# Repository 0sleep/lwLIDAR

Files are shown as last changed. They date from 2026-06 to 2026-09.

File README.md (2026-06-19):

# lwLIDAR

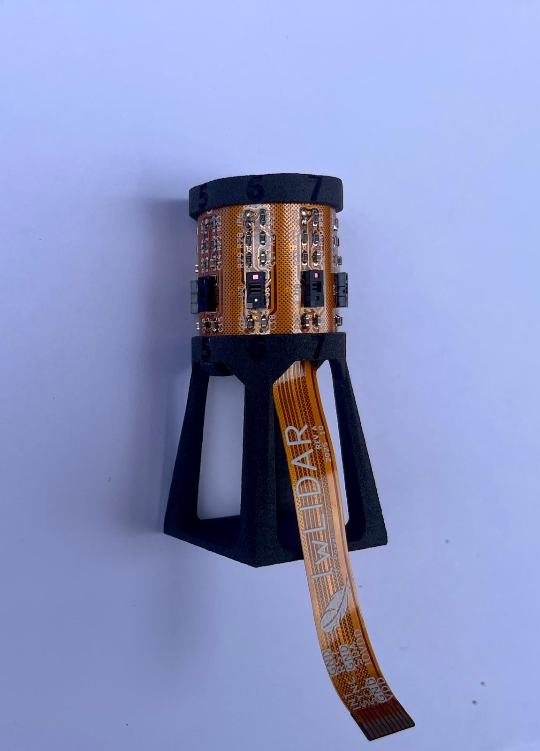
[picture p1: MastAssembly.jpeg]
Image of sensor assembly

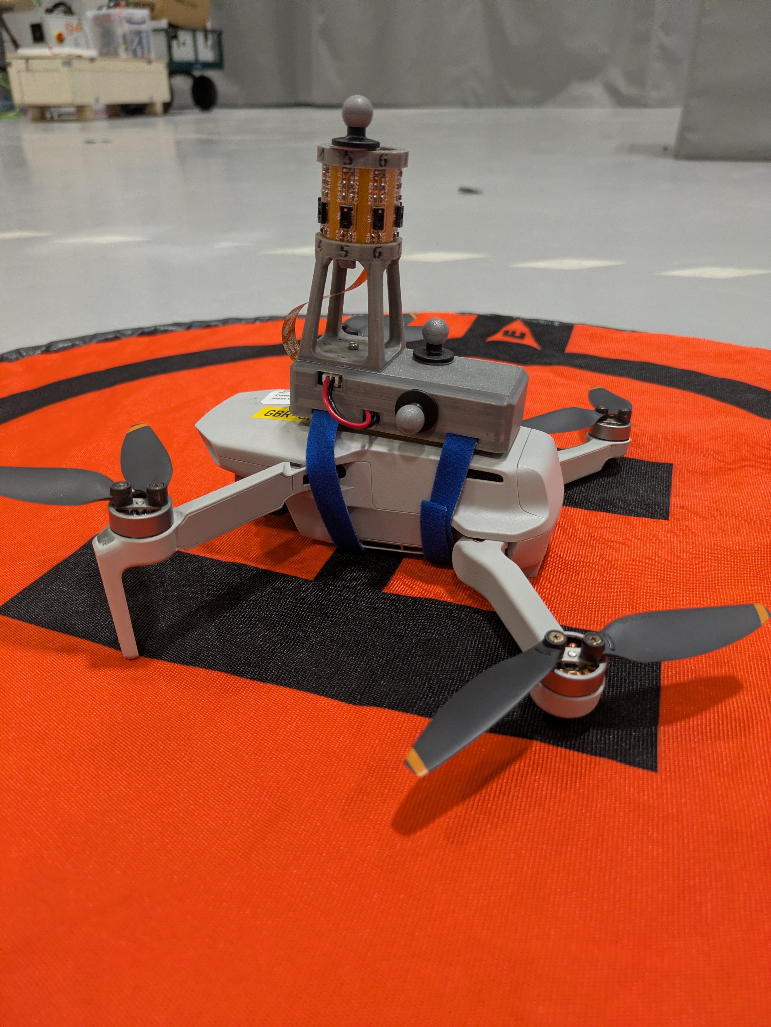
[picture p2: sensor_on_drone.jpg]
Image of sensor mounted to a drone


# Summary
lwLIDAR is a research project aiming to design, implement and test a low-cost compact 3D LiDAR for use in constrained robotics research. It consists of an array of 8 VL53L8CX 8x8 matrix LiDAR sensors mounted to a flexible PCB.

# Repository structure
This repository contains all required design files to construct and program a lwLIDAR sensor with an interface board to act as a sample implementation. Each subdirectory contains a more detailed README file.
- Flex - lwLIDAR core sensor PCB
- Rigid - interface board PCB
- Mechanical - 3D CAD files
- Firmware - example firmware to be run on interface board
- Software - example software to visualise live data

# Performance
|-------------------|-------------------------|
| Framerate         | 16 Hz                   |
| Maximum distance  | 4 m                     |
| Resolution        | 8 v x256 h              |
| FoV               | 45° v x 360° h          |
| Size              | 31x31x67 mm (with mast) |
| Weight            | 11g                     |
| Power consumption | 1.5W                    |
|-------------------|-------------------------|

# License
This project is licensed under the GNU AGPL license (see LICENSE.txt).

# Contributing
If you have improvements or want this repo to link to a usecase you made, please submit a pull request! If you have problems, please open an issue - I'm happy to improve this repository over time!

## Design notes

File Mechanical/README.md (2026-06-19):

# Mechanical design
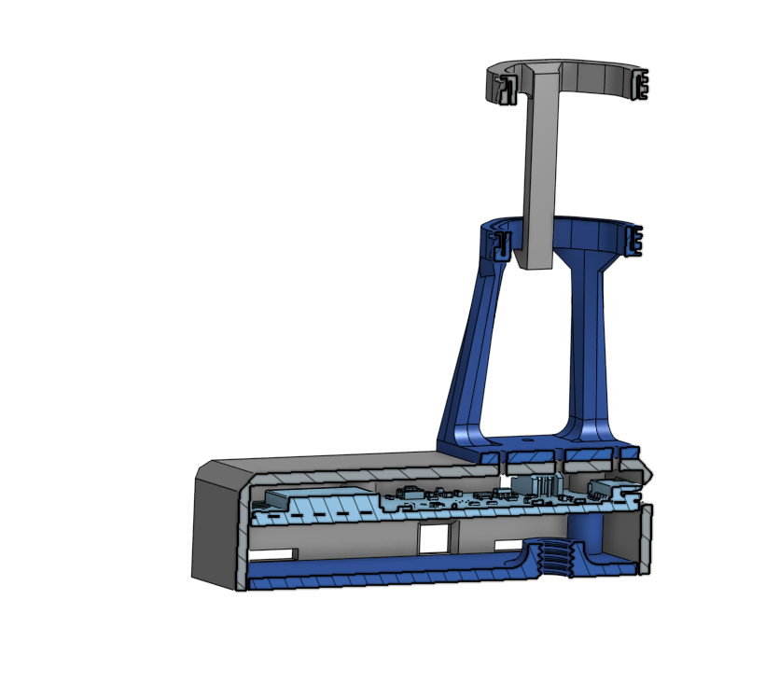
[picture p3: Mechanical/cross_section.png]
Cross-section of CAD design

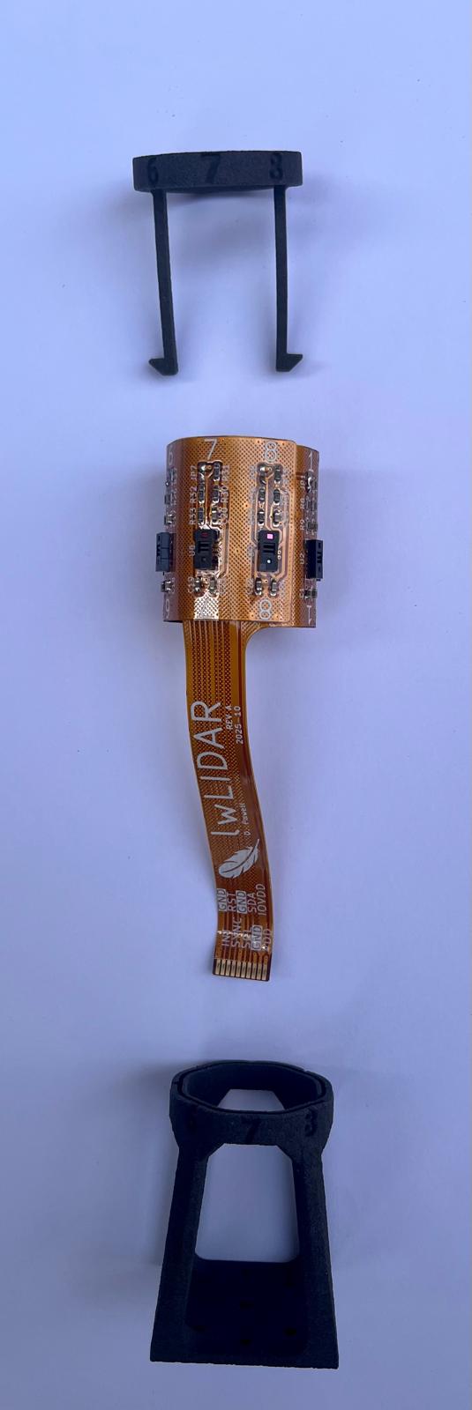
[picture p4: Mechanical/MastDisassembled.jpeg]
The sensor array clips together

The main important part of the mechanical design is the components constraining the flexible PCB. These are named `Flex PCB mast` and `Flex PCB top ring`. In a constrained application, it may be necessary to redesign these to fit better. To this end, there is also a `Flex PCB reference shape` provided, if one wants to start from scratch. It is generated by importing the Flex PCB outline layer from the Flex subdirectory into 3D CAD, and pretending it's a sheet metal part. As well as the Flex PCB constraining parts, there is also `Case Lid` and `Case Body`, which are designed to fit around the interface board, providing a 1/4-20 UNC thread for tripod mounting as well as slots for zip-ties.

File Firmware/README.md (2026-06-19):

# Firmware
This part is a sample implementation of the firmware. It aims to read the sensors in the array as fast as possible (16Hz@8x8 zones). The main program flow is as follows (see also Firmware/components/thesis/thesis.c)

## Setup
for ST's library, set these options:
```
#define VL53L8CX_DISABLE_SIGNAL_PER_SPAD
#define VL53L8CX_DISABLE_REFLECTANCE_PERCENT
#define VL53L8CX_DISABLE_RANGE_SIGMA_MM
#define VL53L8CX_DISABLE_MOTION_INDICATOR
```

This reduces message overhead, as the esp32's maximum i2c clock speed is 400kHz. This means bus space is very tight. On other systems, i2c clock speeds of 1MHz would allow this extra information to also be read out.

Initialise the GPIO expander:

- set all pins to OUTPUT
- set all pins to follow register 0x05
- set all pins to LOW. This disables all sensors' i2c interface

Initialise each sensor:

- set GPIO expander pin belonging to sensor to HIGH
- set sensor I2C address. NOTE: this is being done "manually" in this implementation rather than using rjrrp's esp-idf component, as that implementation is bugged :)
- upload ST's ULD sensor firmware over I2C. This must be done per-sensor after each power-up.
- set sensor resolution to 8x8
- set ranging frequency to 20
- enable external SYNC pin

## Ranging
- For each sensor, start ranging
- Wait 100ms to allow sensors enough time to start up
- Loop (should be done in a high-priority thread to ensure precise timing):
    - wait such that loop speed is limited to 16 Hz
    - turn on SYNC pin for 1 ms
    - wait for the first sensor's interrupt pin to flip. done with an ISR and semaphore in this implementation
    - for each sensor in order:
        - check data is ready (vl53l8cx_check_data_ready)
        - wait for all i2c transactions to complete
        - get ranging data
    - delay 10 ms

# Configuration
WiFi access point information is configured in components/thesis/include/comms.h

SYNC and INT pins are set in components/thesis/include/thesis.h.

# Firmware layout
This is a quick diagram of the tasks performed by this firmware
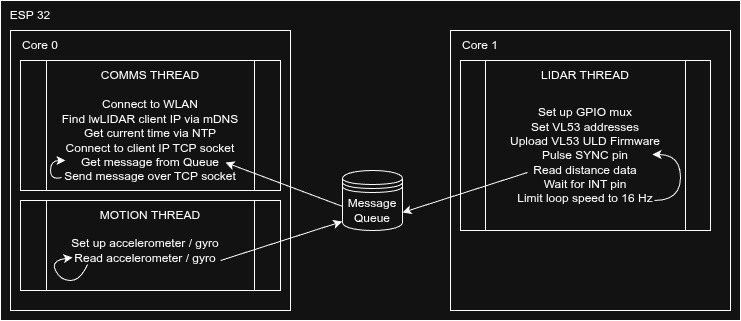
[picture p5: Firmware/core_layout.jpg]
diagram


# Timing
As previously mentioned, it *is* possible to read all sensors at maximum resolution at 16Hz over an I2C bus running at "only" 400kHz, but precise timing is *very important* (because of available bandwidth):

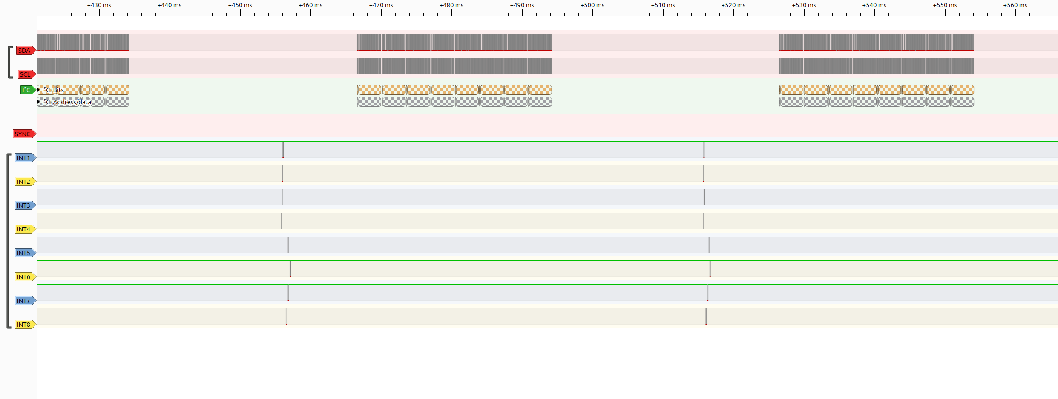
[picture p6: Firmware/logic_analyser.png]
i2c timing


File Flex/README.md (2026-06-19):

# Flex
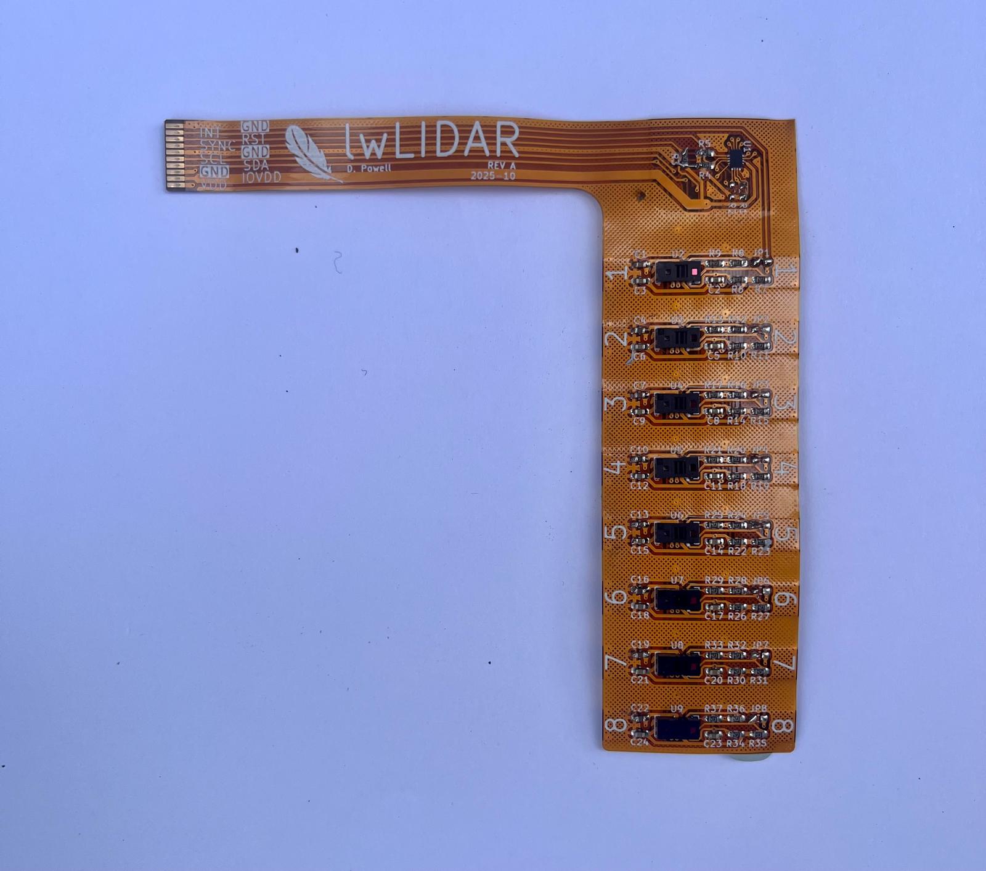
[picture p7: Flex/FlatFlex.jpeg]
Flattened sensor array

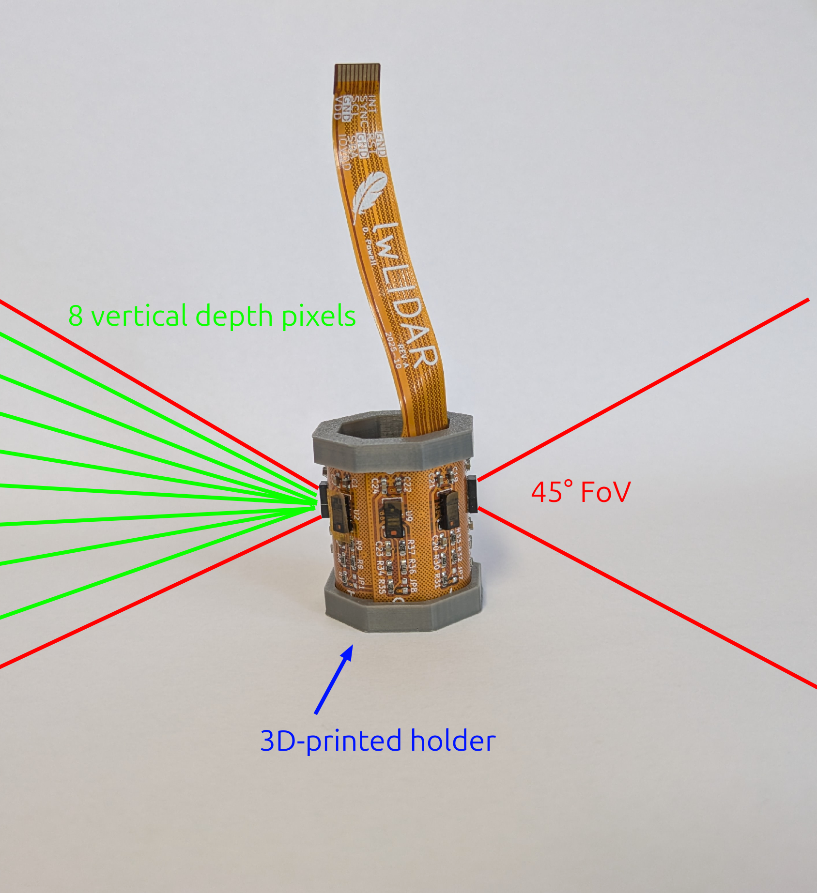
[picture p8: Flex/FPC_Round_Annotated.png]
Assembled sensor array with FoV


This directory contains the KiCAD project files for the flexible PCB. It is only 8 VL53L8CX as well as an I2C GPIO expander. The stiffener layer should be 0.25mm polyimide to ensure the PCB (2 layer, 25um) fits in the molex connector [easy-on 1mm pitch 10 circuits](https://www.molex.com/en-us/products/part-detail/522071060). The PCB fits inside a 100mmx100mm square area to minimise PCB production costs. All passive components are hand-solderable 0603.

# Issues
The state of this directors is as-created for the thesis. This means that the I2C pullups are incorrectly set to pull up to VDD (3.3V), when they should be pulling to IOVDD (1.8V). To save production cost, only PI stiffeners are used. However, to provide better heat wicking from the sensors, it may be advisable to use stainless steel stiffeners behind the sensors. (Avoid stainless steel stiffener on the connector part, it will short out the connector!)

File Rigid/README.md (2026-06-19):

# FR4
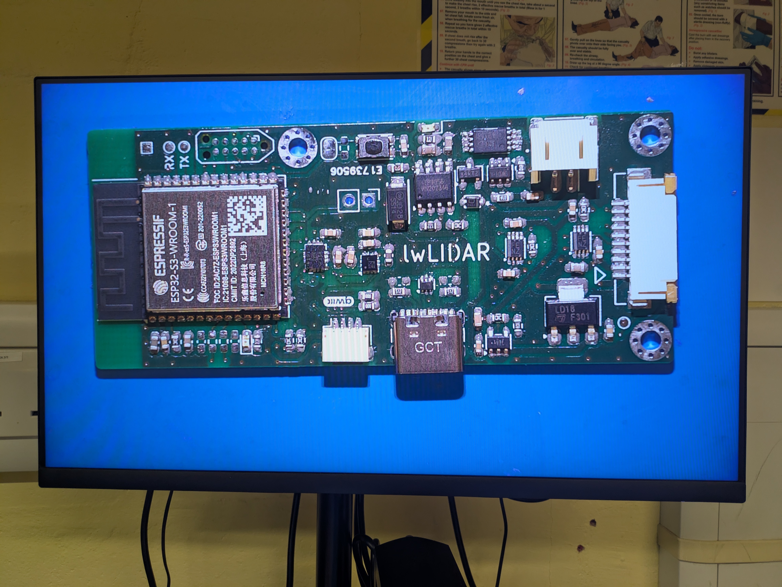
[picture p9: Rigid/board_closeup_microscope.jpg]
Close-up image of board under lab microscope


This repo contains the rigid part of the lwLIDAR system. It is intended to act as a sample interface design. In a "proper" application, the functionality provided by this board would be implemented as part of the main device (e.g. on a small drone, this would be handled on the drone motherboard.)

# Features
This component provides a power and data interface to the flex PCB, a microcontroller to demonstrate functionality, as well as auxiliary components. The microcontroller is an esp32-s3 module, which allows wireless data streaming and simple USB programming.

Required for sensor operation:
- 3.3V power supply
- 1.8V logic power supply
- I2C bus (400kHz, 1.8V)
- interrupt pin to MCU @ 1.8V
- sync pin to flex PCB @ 1.8V

Additionally:
- Accelerometer / Gyro
- Magnetometer
- TP4056 BMS w/ automatic power switching
- QUIIC port

# Issues
- Power supply is based on low-dropout regulators. During operation, these will get very hot. Ideally, this would be implemented with a switching buck converter.
- No reset button (only boot button), which makes recovery of the esp32 annoying.
- No polarity markings on the battery connector. JST 2-pin battery polarity is NOT STANDARDISED!
- No facility to monitor battery voltage.

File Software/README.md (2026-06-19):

# Software
This software is intended to be run on a separate computer. It opens a TCP port on 3133, figures out its own IP address, and then broadcast it via mDNS. This allows the firmware on the esp32 to find it and connect. Then, received data is passed to Viser, which renders it live in a browser tab.

This program is meant to be a reference implementation only. In a "perfect implementation", this program is not necessary, as the robotic system itself passes the sensor data straight into a message bus system, e.g. ROS or LN.

The idea to use Viser and geom.py are taken from [this lovely repo](https://github.com/ferrolho/VL53L5CX-BNO08X-viewer/) by Henrique Ferrolho, who happened to publish a [video](https://www.youtube.com/watch?v=s32OUzhjf4U) using the same base sensor while I was working on this project.

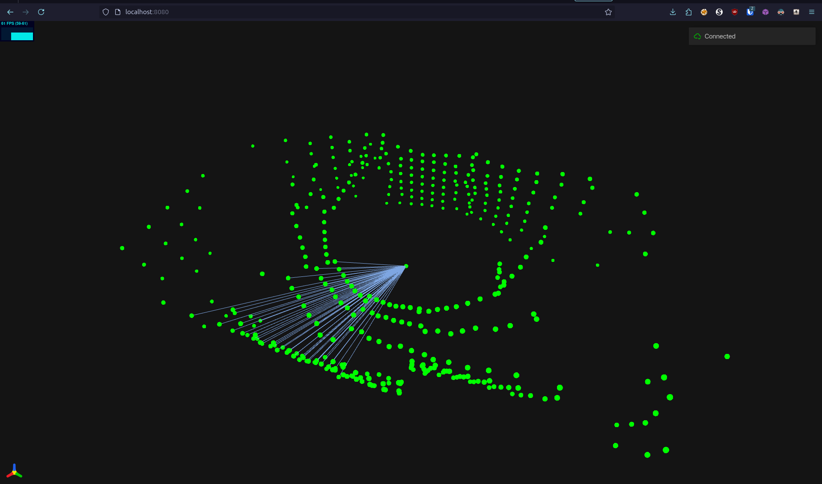
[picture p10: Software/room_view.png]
Approximate user interface


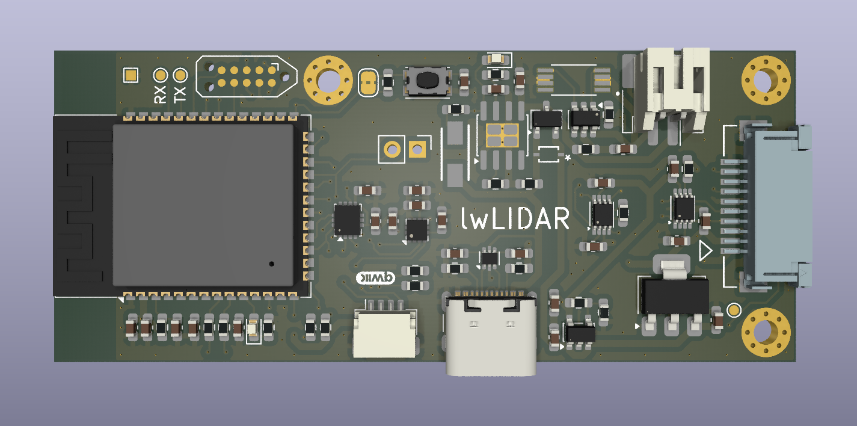
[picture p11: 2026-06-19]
Rigid/mcu_board/render.png

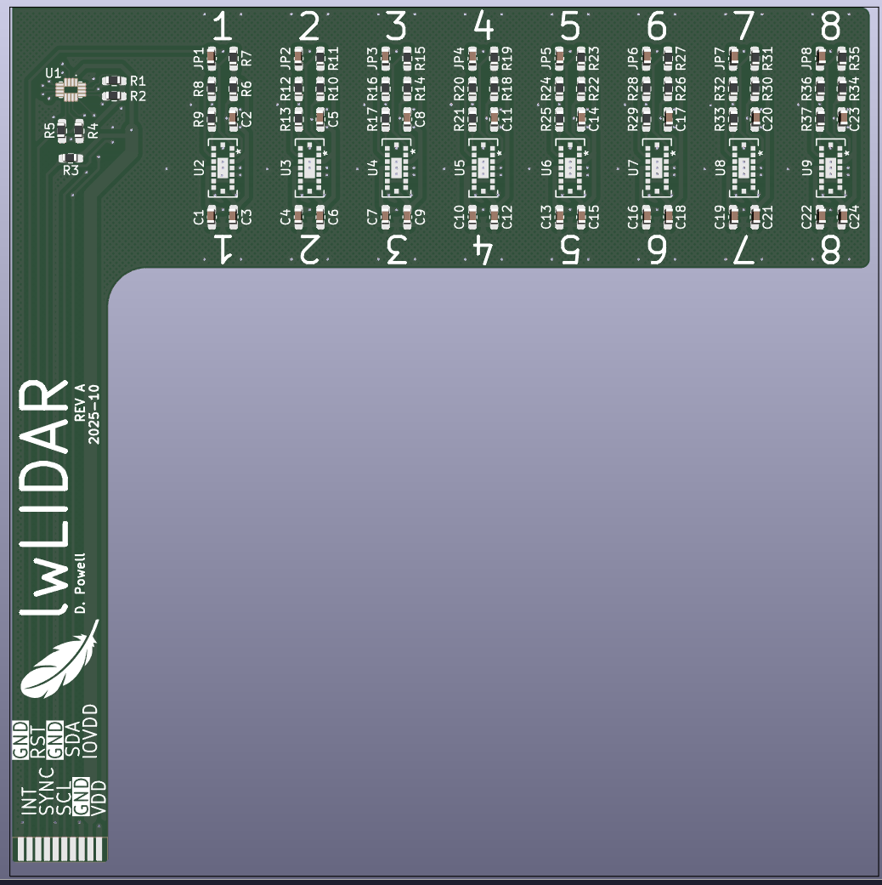
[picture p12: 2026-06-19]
Flex/sensor_board/render.png

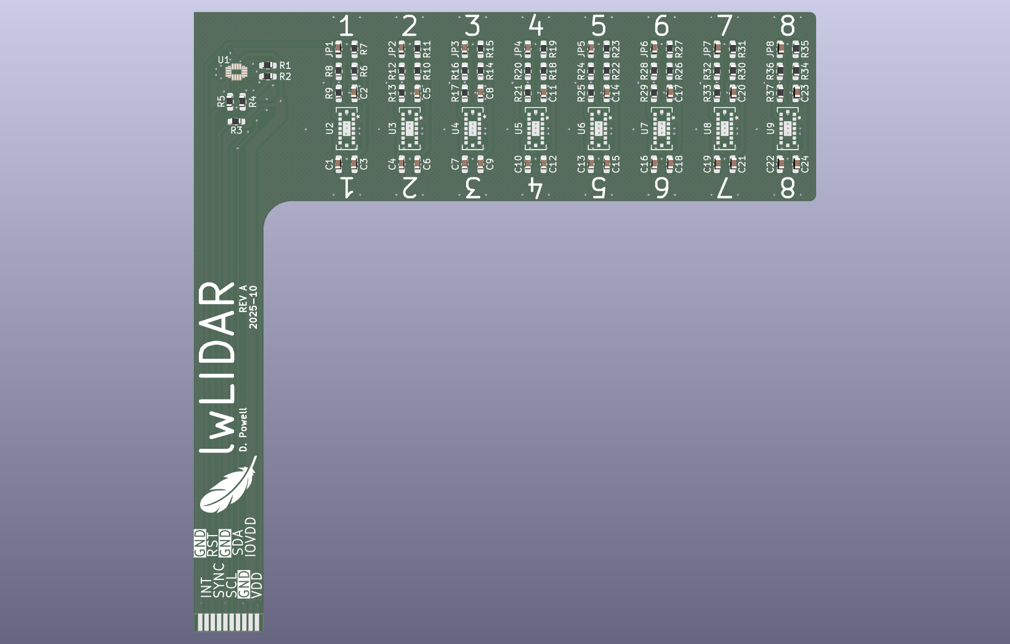
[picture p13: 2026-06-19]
Flex/sensor_board/sensor_board.png

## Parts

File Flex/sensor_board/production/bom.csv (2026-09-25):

Designator | Footprint | Quantity | Value | LCSC Part #
C1, C10, C13, C16, C19, C22, C4, C7 | 0603 | 8 | 4.7uF
C11, C12, C14, C15, C17, C18, C2, C20, C21, C23, C24, C3, C5, C6, C8, C9 | 0603 | 16 | 100nF
J1 | Molex 10 Pin Flex 52207-1060 | 1 | Conn_01x10_Pin
R1, R2 | 0603 | 2 | 10k
R10, R11, R12, R13, R14, R15, R16, R17, R18, R19, R20, R21, R22, R23, R24, R25, R26, R27, R28, R29, R3, R30, R31, R32, R33, R34, R35, R36, R37, R4, R5, R6, R7, R8, R9 | 0603 | 35 | 47k
U1 | QFN40P260X180X55-16N | 1 | FXL6408UMX
U2, U3, U4, U5, U6, U7, U8, U9 | IC17_LGA16_STM | 8 | VL53L7CXV0GC/1

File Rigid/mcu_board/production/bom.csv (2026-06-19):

Designator | Footprint | Quantity | Value | LCSC Part #
C1, C10, C13, C22, C23, C24, C25 | 0603 | 7 | 0.1uF
C11, C12, R12, R22, R23 | 0603 | 5 | DNP
C14, C15, C17, C19, C4, C6 | 0603 | 6 | 100nF
C16 | 0603 | 1 | 220nF
C18, C2, C3, C5 | 0603 | 4 | 10uF
C20, C21 | 0603 | 2 | 12pf NC
C7 | 0603 | 1 | 100uF
C8 | 0603 | 1 | 1uF
C9 | 0603 | 1 | 22uF
D1, D3 | 0603 | 2 | LED
D2 | DIO_RB500V_ROM | 1 | RB551VM-30
D4 | DIOM5227X270N | 1 | SS14
J1 | JST_PH_S2B-PH-SM4-TB_1x02-1MP_P2.00mm_Horizontal | 1 | Conn_01x02_MountingPin
J2 | USB_C_Receptacle_GCT_USB4105-xx-A_16P_TopMnt_Horizontal | 1 | USB_C_Receptacle_USB2.0_16P
J4 | CON_522071060_MOL | 1 | Molex 522071060
J5 | JST_SH_SM04B-SRSS-TB_1x04-1MP_P1.00mm_Horizontal | 1 | QUIIC connector
J6 | PinHeader_1x02_P2.54mm_Vertical | 1 | Conn_01x02
MH1, MH2, MH3 | MountingHole_2.5mm_Pad_Via | 3 | Conn_01x01
Q1 | SOP65P640X120-8N | 1 | FS8205A
Q2 | TSOT-23 | 1 | DMP1045U
R1, R2 | 0603 | 2 | 5.1k
R10, R11 | 0603 | 2 | 0R
R13, R14, R15, R21, R6, R7, R9 | 0603 | 7 | 10k
R16, R17, R18 | 0603 | 3 | NC
R19, R5 | 0603 | 2 | 330R
R20 | 0603 | 1 | 0.4R
R3 | 0603 | 1 | 100R
R4 | 0603 | 1 | 1k
R8 | 0603 | 1 | 2k
RX, TP1, TX | TestPoint_Pad_D1.0mm | 3 | TestPoint
R_PROG1 | 0603 | 1 | 1.2k
SW1 | SW_Push_1P1T_NO_CK_KMR2 | 1 | SW_Push
TP4 | TestPoint_Pad_1.0x1.0mm | 1 | TestPoint
U1 | ESP32-S3-WROOM-1 | 1 | ESP32-S3-WROOM-1
U10, U8 | VSSOP-8_2.3x2mm_P0.5mm | 2 | TXS0102DCU
U2 | LGA-14_3x2.5mm_P0.5mm_LayoutBorder3x4y | 1 | LSM6DSO
U3 | LGA-12_2x2mm_P0.5mm | 1 | LIS2MDL
U4 | SOT-23-6 | 1 | DW01A
U5 | SOIC-8-1EP_3.9x4.9mm_P1.27mm_EP2.41x3.3mm_ThermalVias | 1 | TP4056-42-ESOP8
U6 | SOT-223-3_TabPin2 | 1 | LD1117S18TR_SOT223
U7 | SOT-23-5 | 1 | TLV75801PDBV
U9 | SOT-666 | 1 | USBLC6-2P6
Y1 | Crystal_SMD_SeikoEpson_MC306-4Pin_8.0x3.2mm | 1 | NC

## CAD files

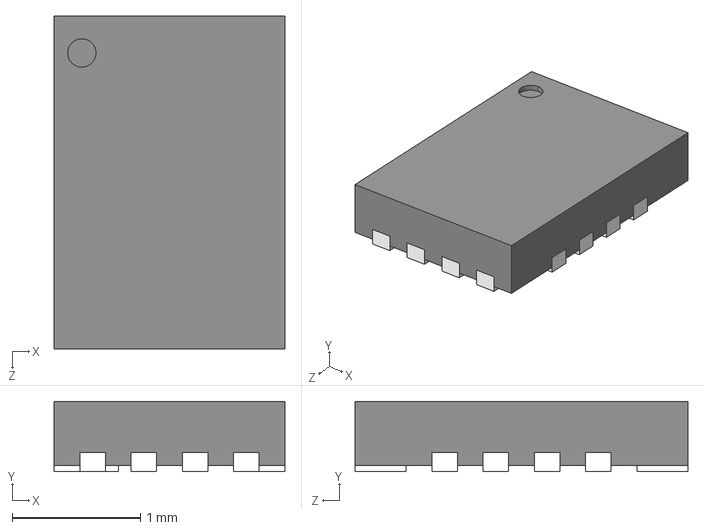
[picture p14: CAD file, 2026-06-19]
Flex/sensor_board/Parts/FXL6408UMX/FXL6408UMX.step
1.80 x 0.55 x 2.60 mm

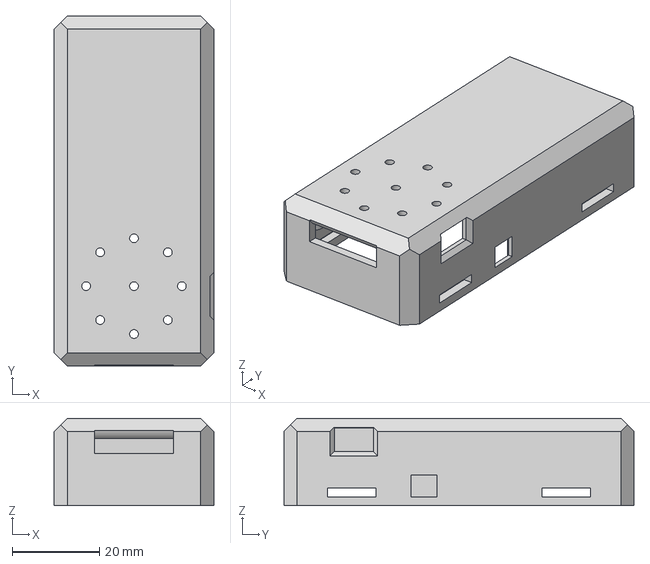
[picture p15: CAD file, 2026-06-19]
Mechanical/Case body.step
36.5 x 80.0 x 20.0 mm

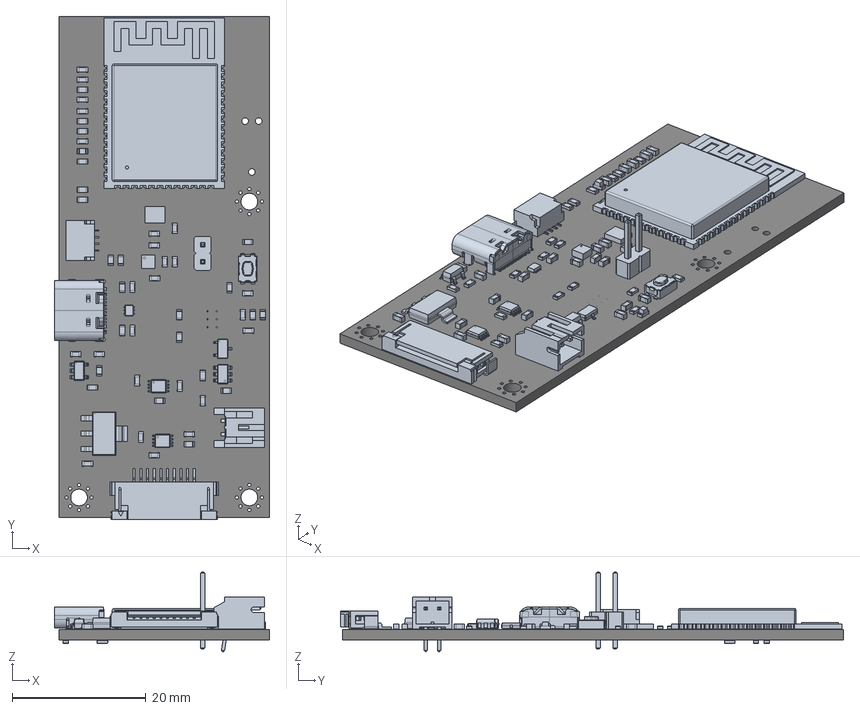
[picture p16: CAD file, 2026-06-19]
Rigid/mcu_board/mcu_board.step
32.2 x 75.3 x 11.9 mm
LED_0603_1608Metric x 2
C_0603_1608Metric x 25
R_0603_1608Metric x 24
LGA-14_3x2.5mm_P0.5mm_LayoutBorder3x4y
SW_Push_1P1T_NO_CK_KMR2
SOT-223
TSOT-23
SOT-23-6
VSSOP-8_2.3x2mm_P0.5mm x 2
JST_SH_SM04B-SRSS-TB_1x04-1MP_P1.00mm_Horizontal
ESP32-S3-WROOM-1
PinHeader_1x02_P2.54mm_Vertical
LGA-12_2x2mm_P0.5mm
SOT-23-5
JST_PH_S2B-PH-K_1x02_P2.00mm_Horizontal
SOT-666
USB_C_Receptacle_GCT_USB4105-xx-A_16P_TopMnt_Horizontal
mcu_board_PCB

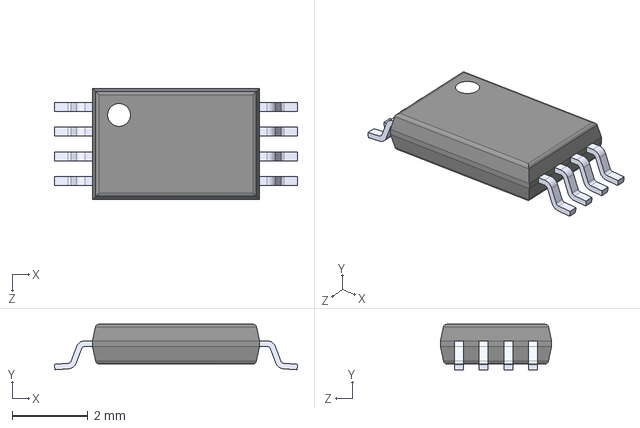
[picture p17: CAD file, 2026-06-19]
Rigid/mcu_board/Parts/FS8205A/FS8205A.step
6.40 x 1.20 x 2.93 mm

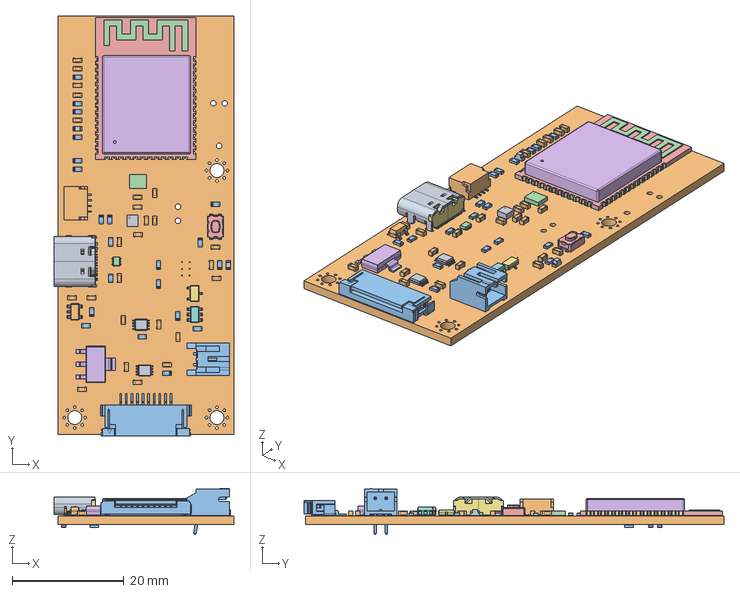
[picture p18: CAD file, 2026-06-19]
Mechanical/Rigid Board CAD.step
32.2 x 75.3 x 8.25 mm

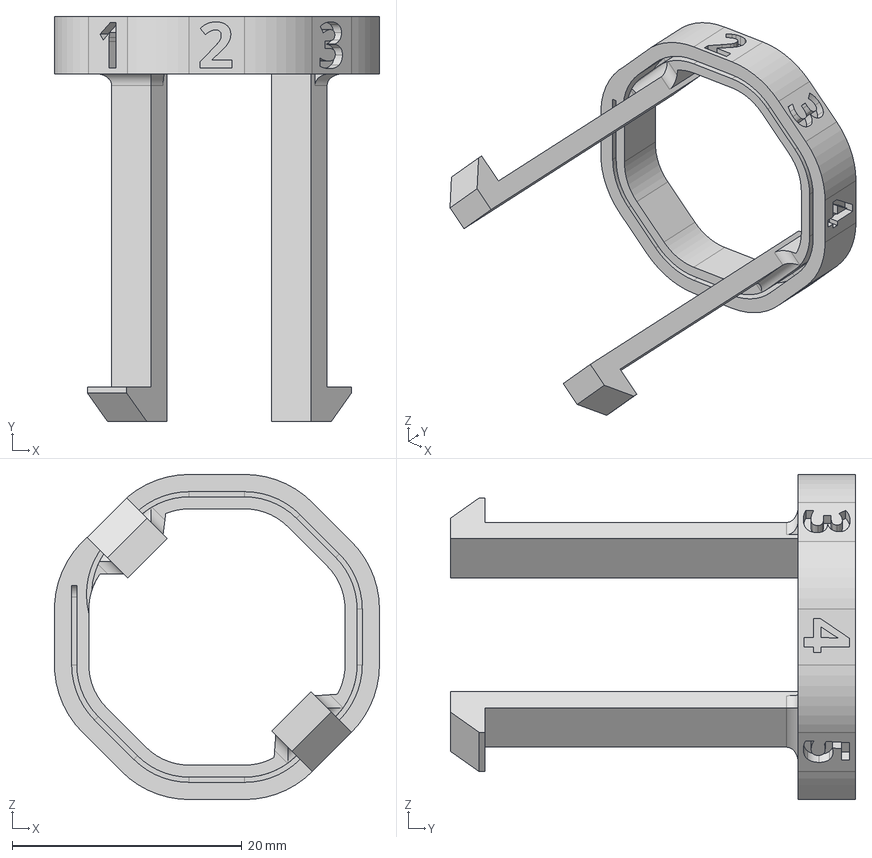
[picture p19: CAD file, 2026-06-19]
Mechanical/Flex PCB top ring.step
28.3 x 35.3 x 28.3 mm

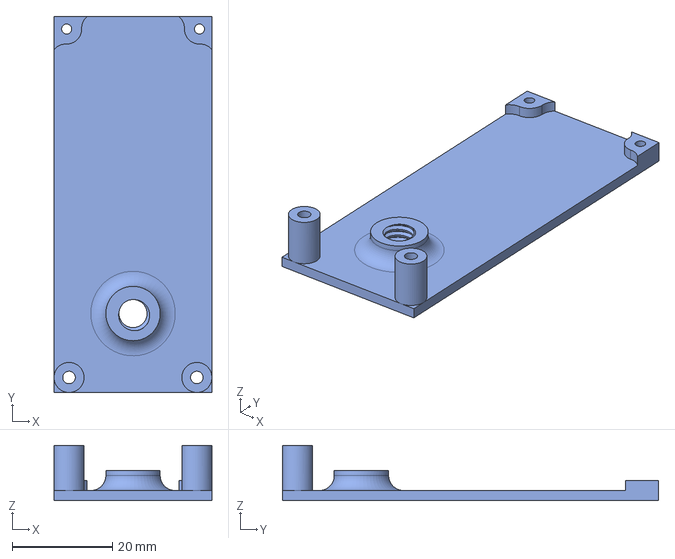
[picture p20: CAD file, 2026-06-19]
Mechanical/Case Lid.step
31.5 x 75.0 x 11.0 mm

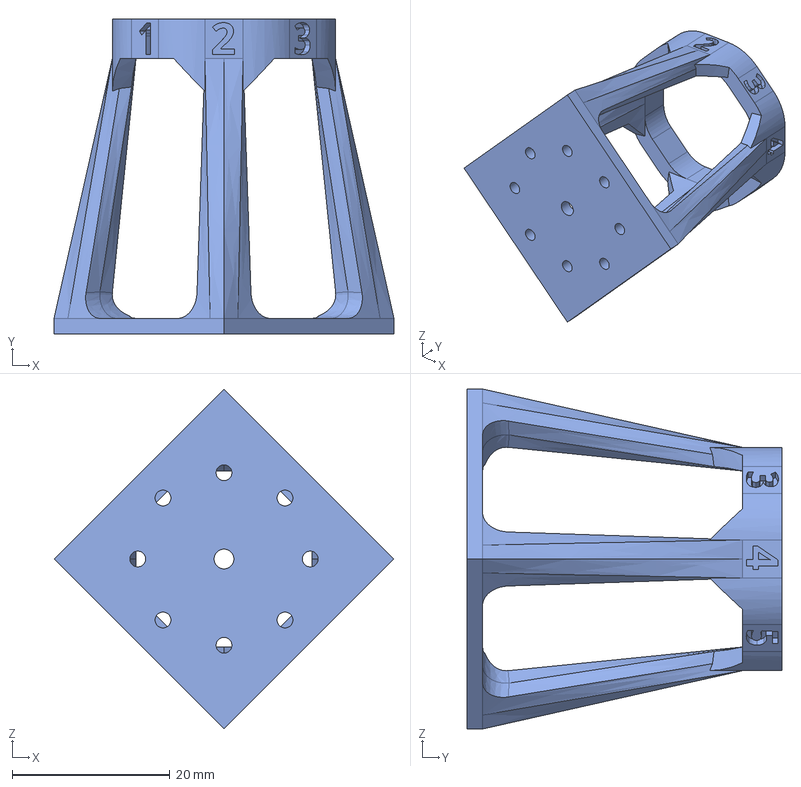
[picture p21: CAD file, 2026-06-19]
Mechanical/Flex PCB mast.step
43.1 x 40.0 x 43.1 mm

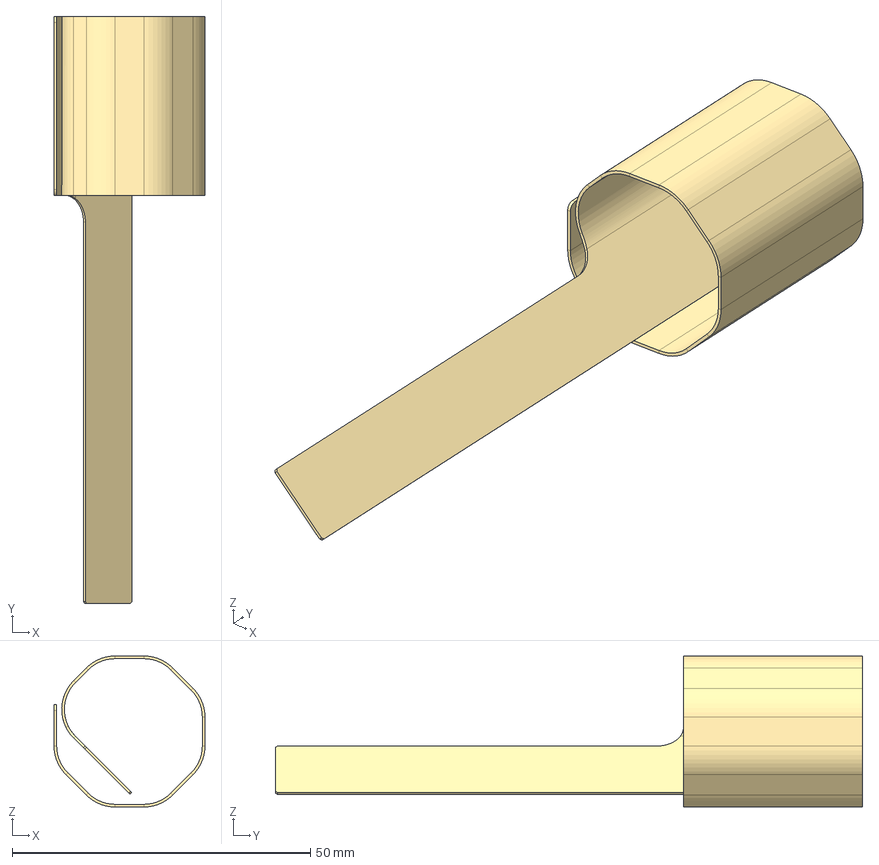
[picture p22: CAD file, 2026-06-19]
Mechanical/Flex PCB reference shape.step
25.3 x 98.4 x 25.3 mm

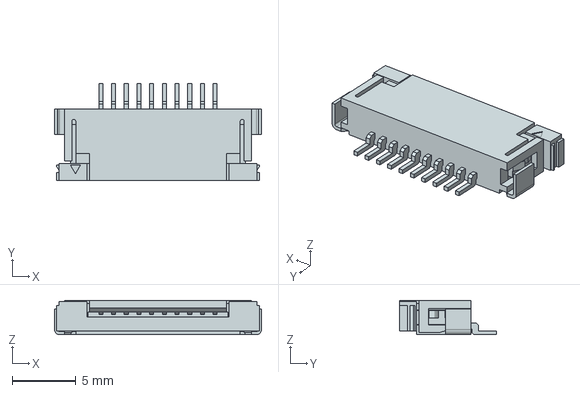
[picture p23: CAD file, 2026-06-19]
Rigid/mcu_board/Parts/Molex 522071060/0522071060.stp
16.3 x 7.60 x 2.70 mm

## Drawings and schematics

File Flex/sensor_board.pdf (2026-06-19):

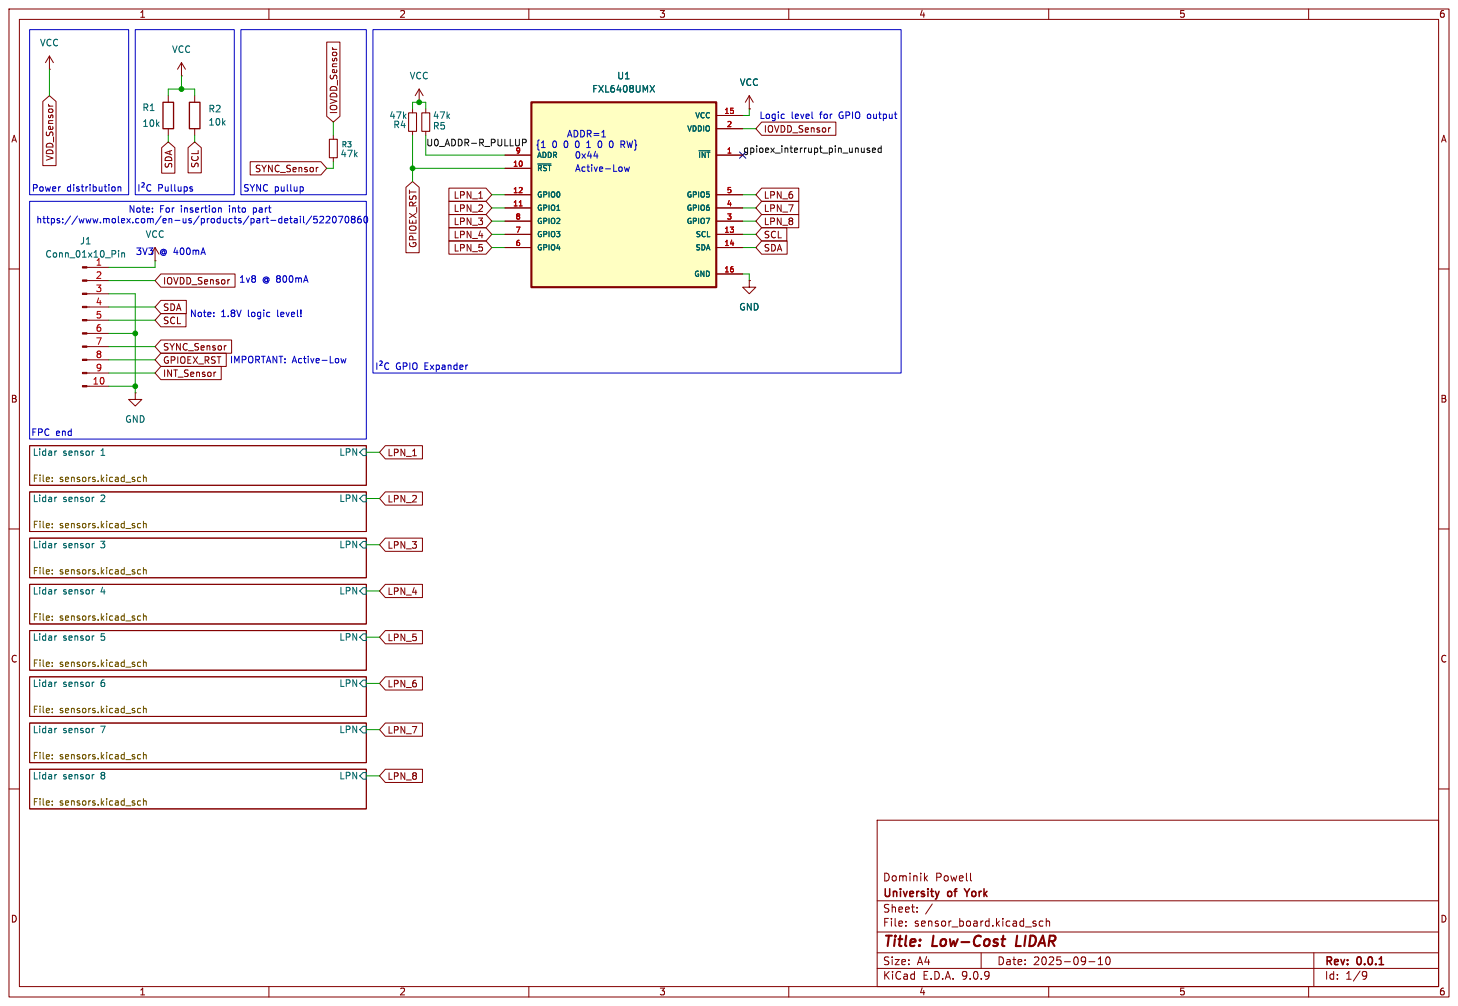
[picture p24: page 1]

Id: 1/9 Title: Low-Cost LIDAR

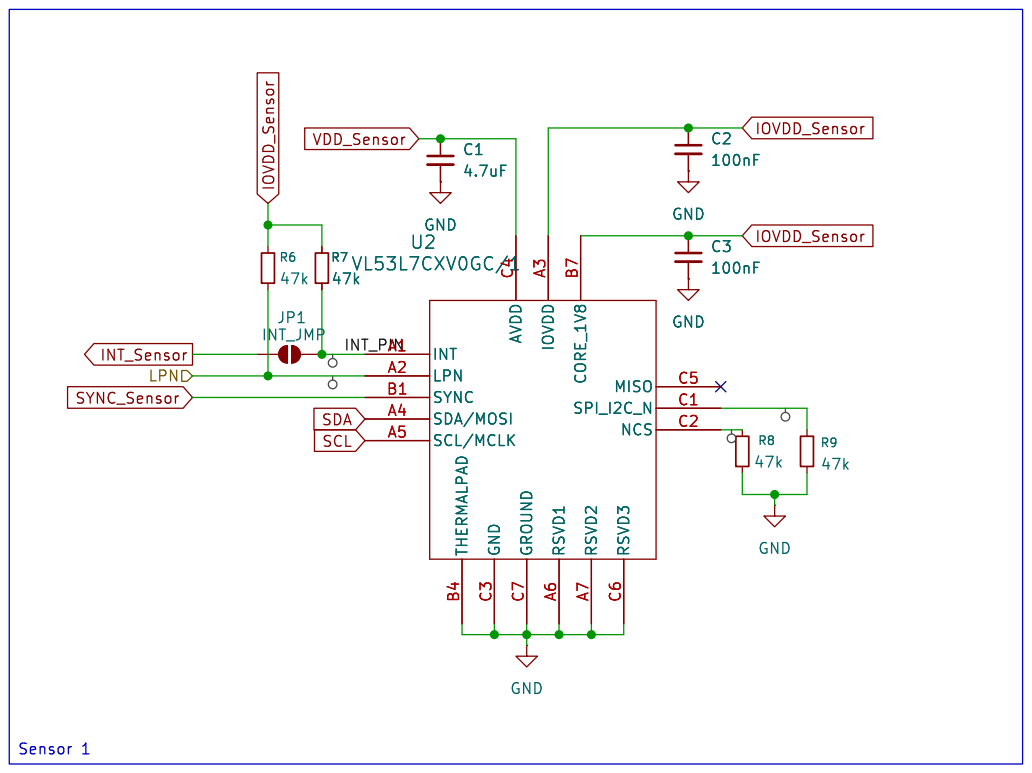
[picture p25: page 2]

Id: 2/9 Title: Sensor Page

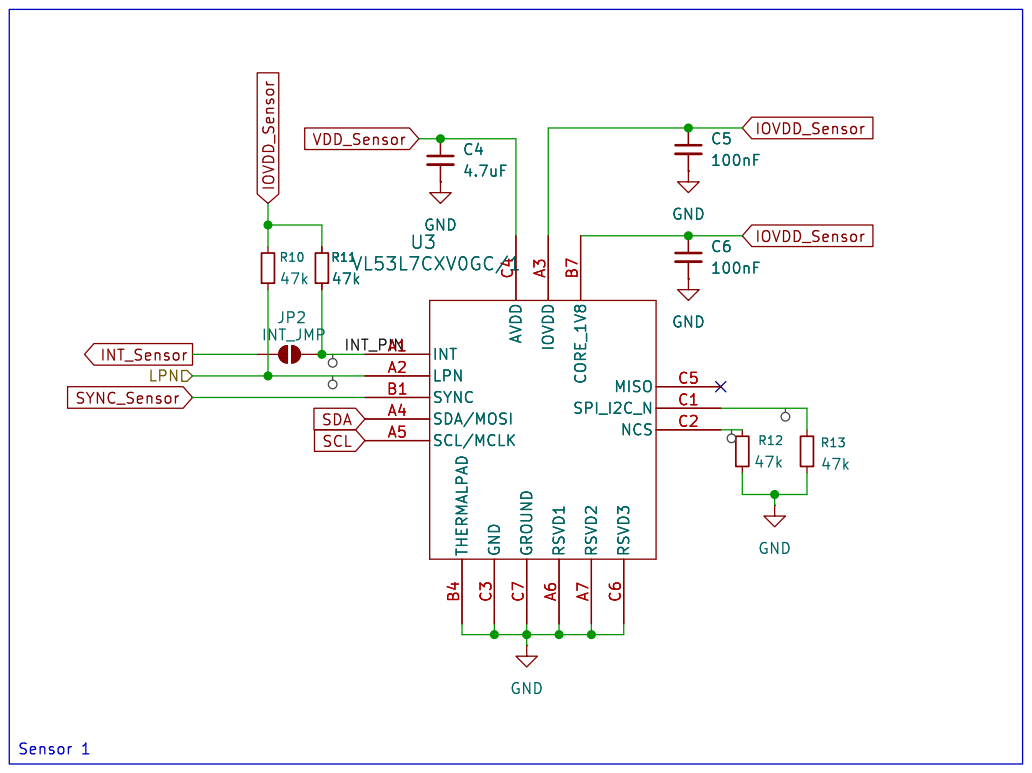
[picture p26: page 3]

Id: 3/9 Title: Sensor Page

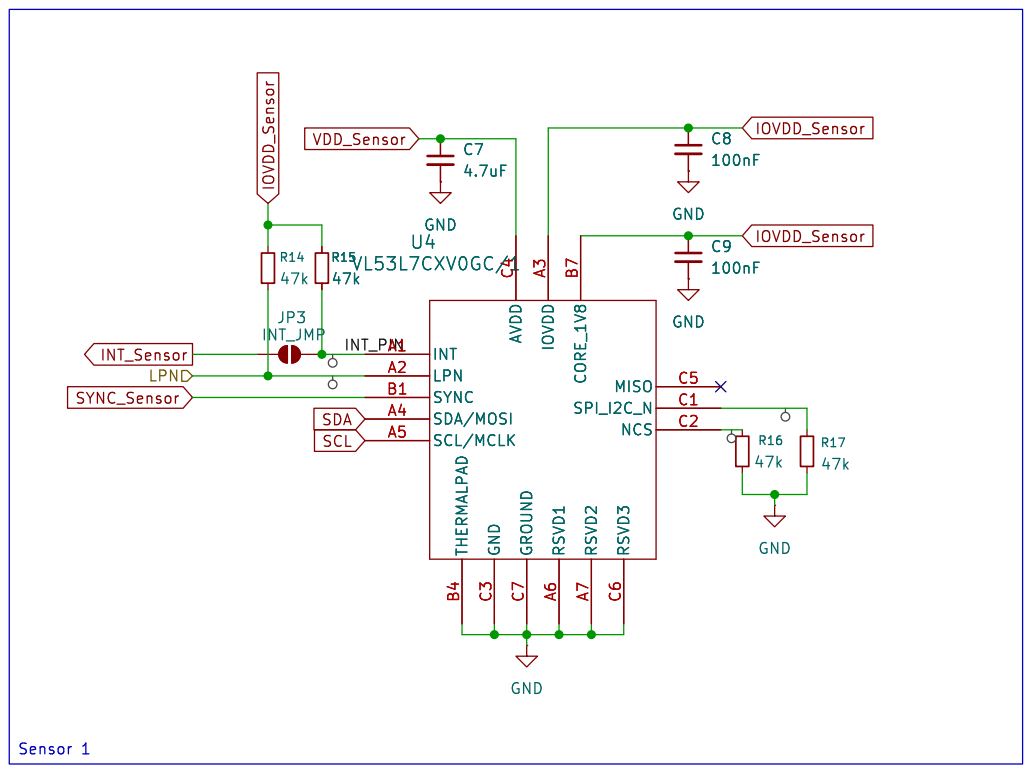
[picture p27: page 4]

Id: 4/9 Title: Sensor Page

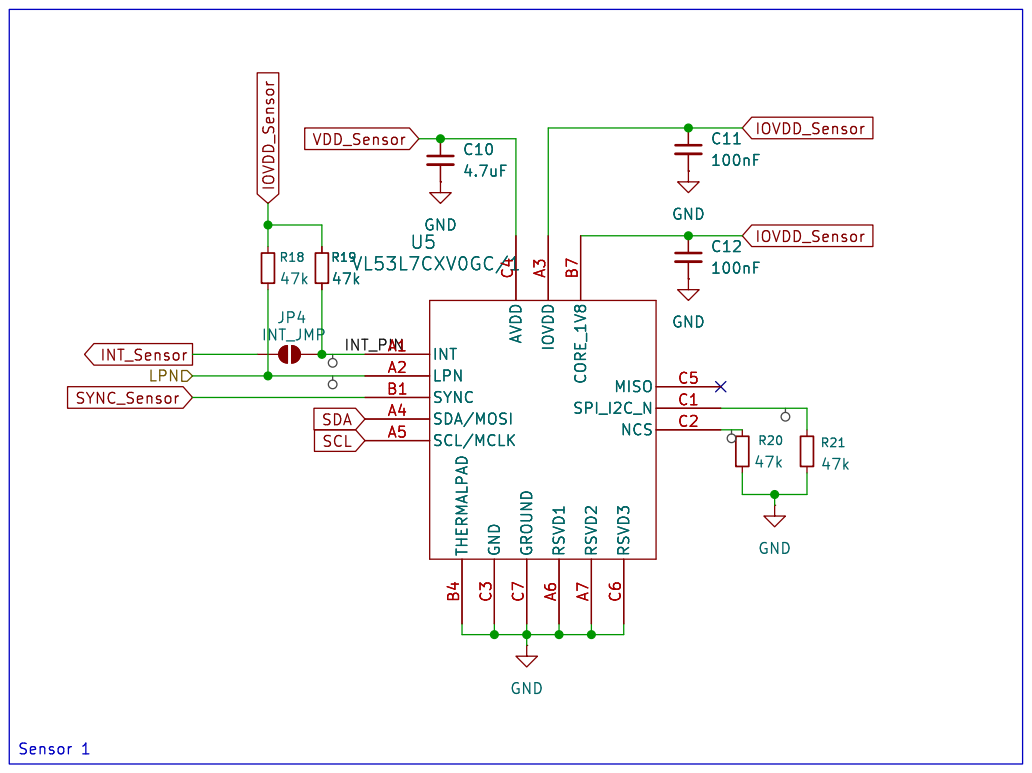
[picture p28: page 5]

Id: 5/9 Title: Sensor Page

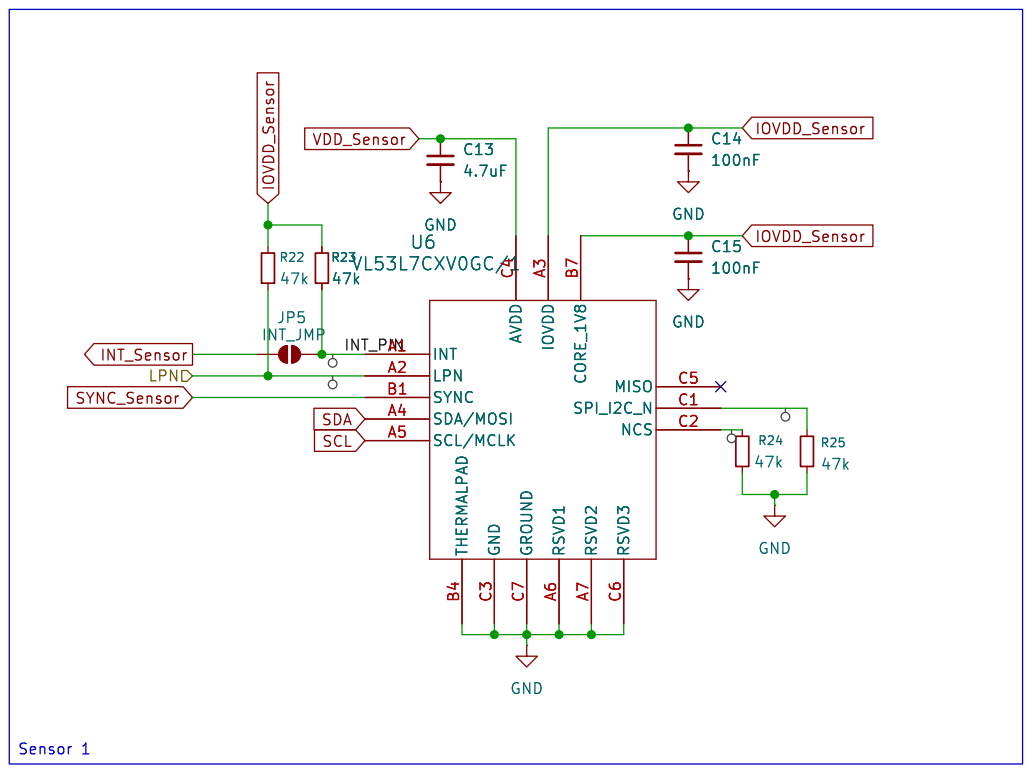
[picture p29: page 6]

Id: 6/9 Title: Sensor Page

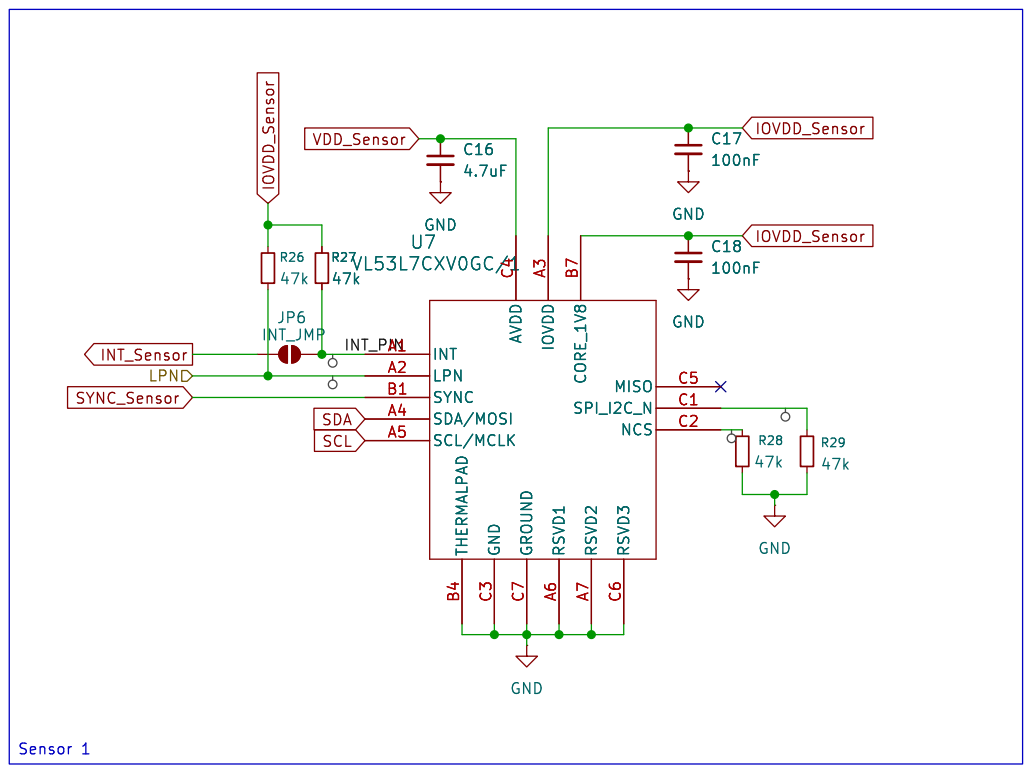
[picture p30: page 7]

Id: 7/9 Title: Sensor Page

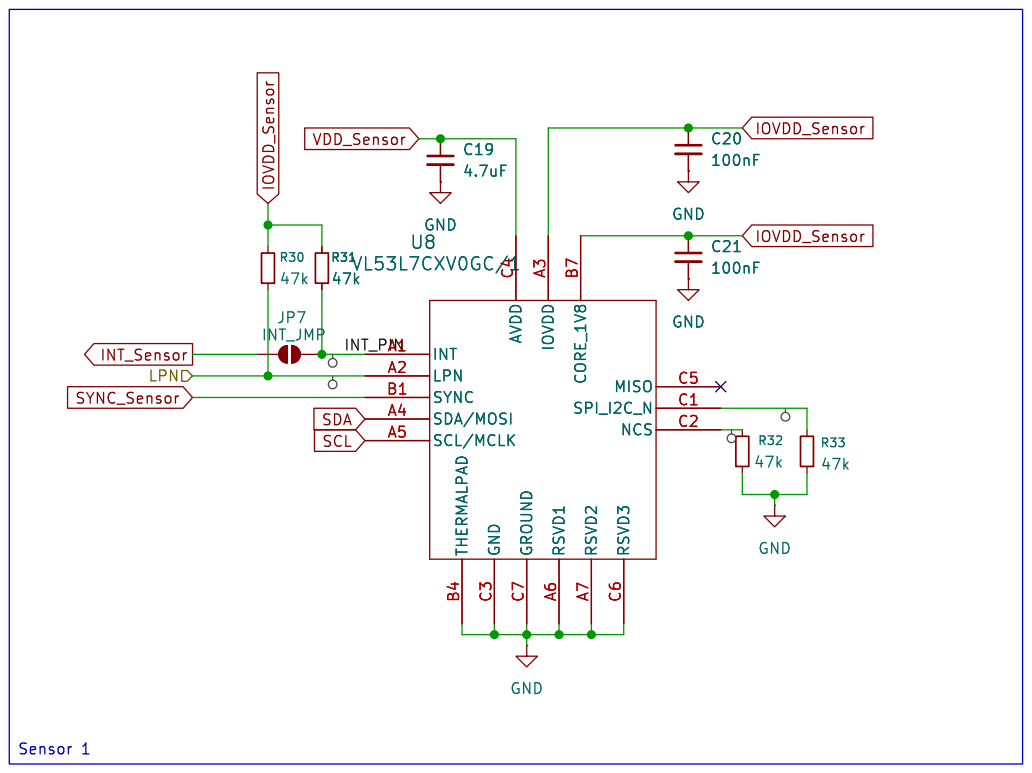
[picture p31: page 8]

Id: 8/9 Title: Sensor Page

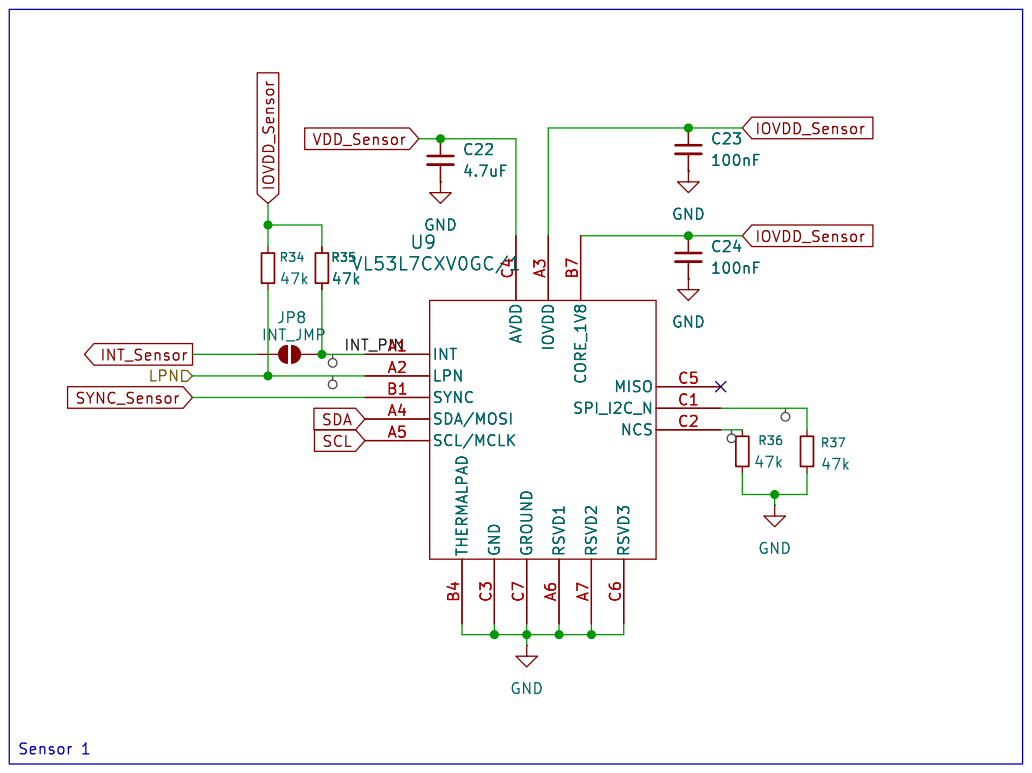
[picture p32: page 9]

Id: 9/9 Title: Sensor Page

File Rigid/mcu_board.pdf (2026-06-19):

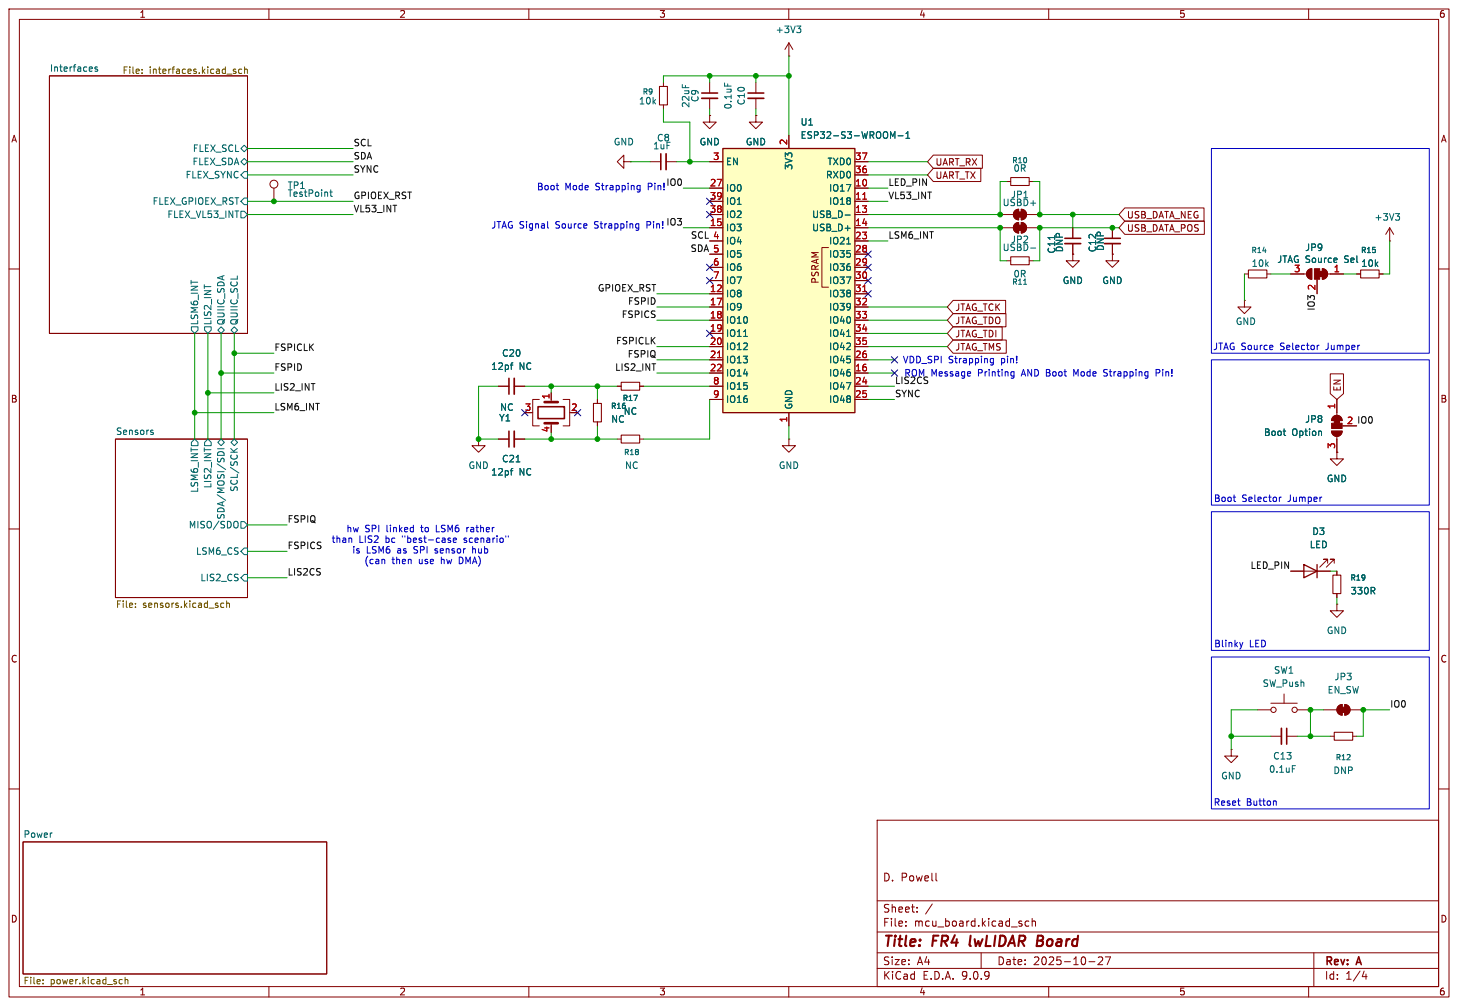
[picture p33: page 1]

JTAG Source Sel PSRAM

LSM6_CS LSM6_INT MISO/SDO SCL/SCK SDA/MOSI/SDI Sensors File: sensors.kicad_sch Power File: power.kicad_sch

hw SPI linked to LSM6 rather
is LSM6 as SPI sensor hub
(can then use hw DMA)

Id: 1/4 Title: FR4 lwLIDAR Board

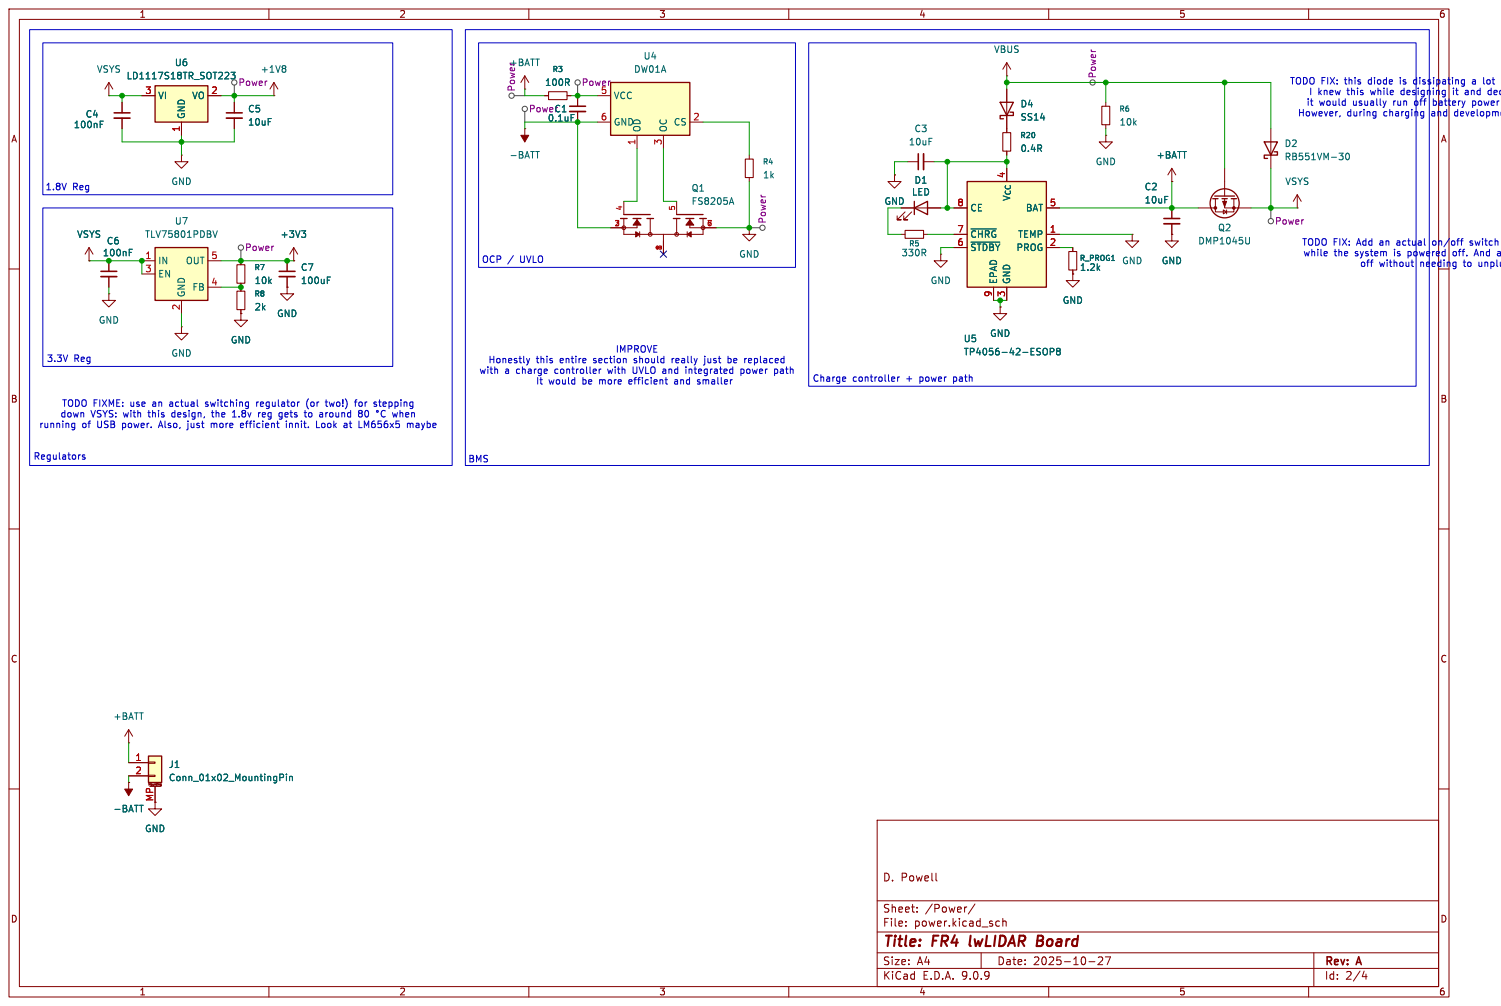
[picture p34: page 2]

3 BAT 5 TEMP 1 PROG 2 U5 TP4056-42-ESOP8 +BATT VCC 5 GND 6 OD

2 OUT 5 FB 4 U7 TLV75801PDBV GND GND

down VSYS: with this design, the 1.8v reg gets to around 80 þÿ°Cwhen

Id: 2/4 Title: FR4 lwLIDAR Board

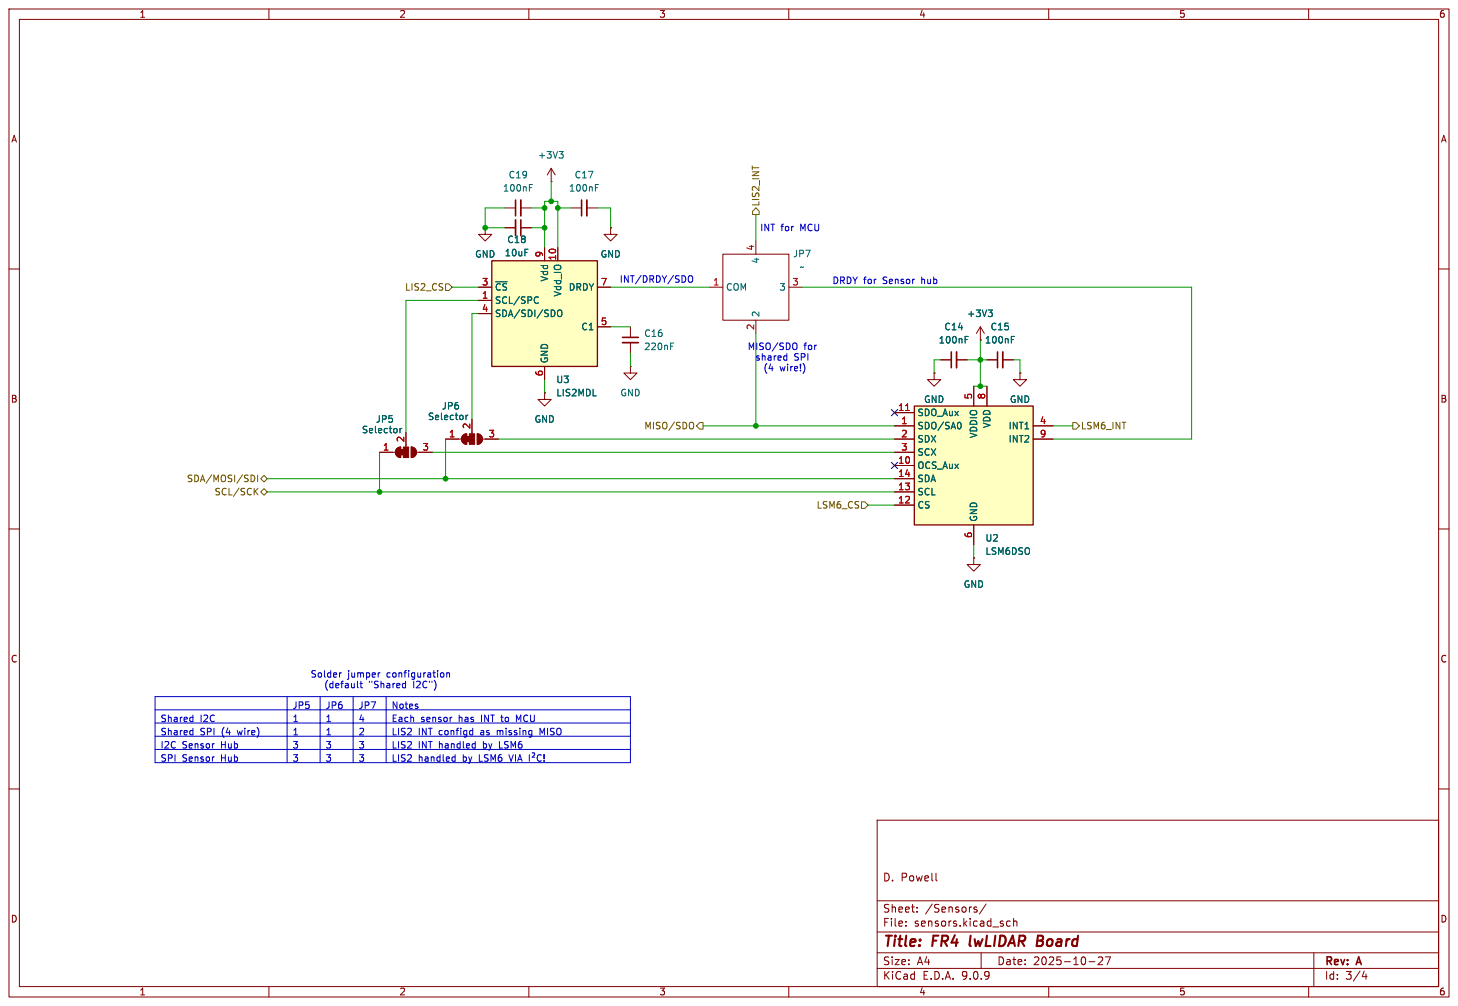
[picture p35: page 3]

DRDY for Sensor hub Solder jumper configuration

Id: 3/4 Title: FR4 lwLIDAR Board


1 MH1 Conn_01x01 GND GND GND GND

Id: 4/4 Title: FR4 lwLIDAR Board




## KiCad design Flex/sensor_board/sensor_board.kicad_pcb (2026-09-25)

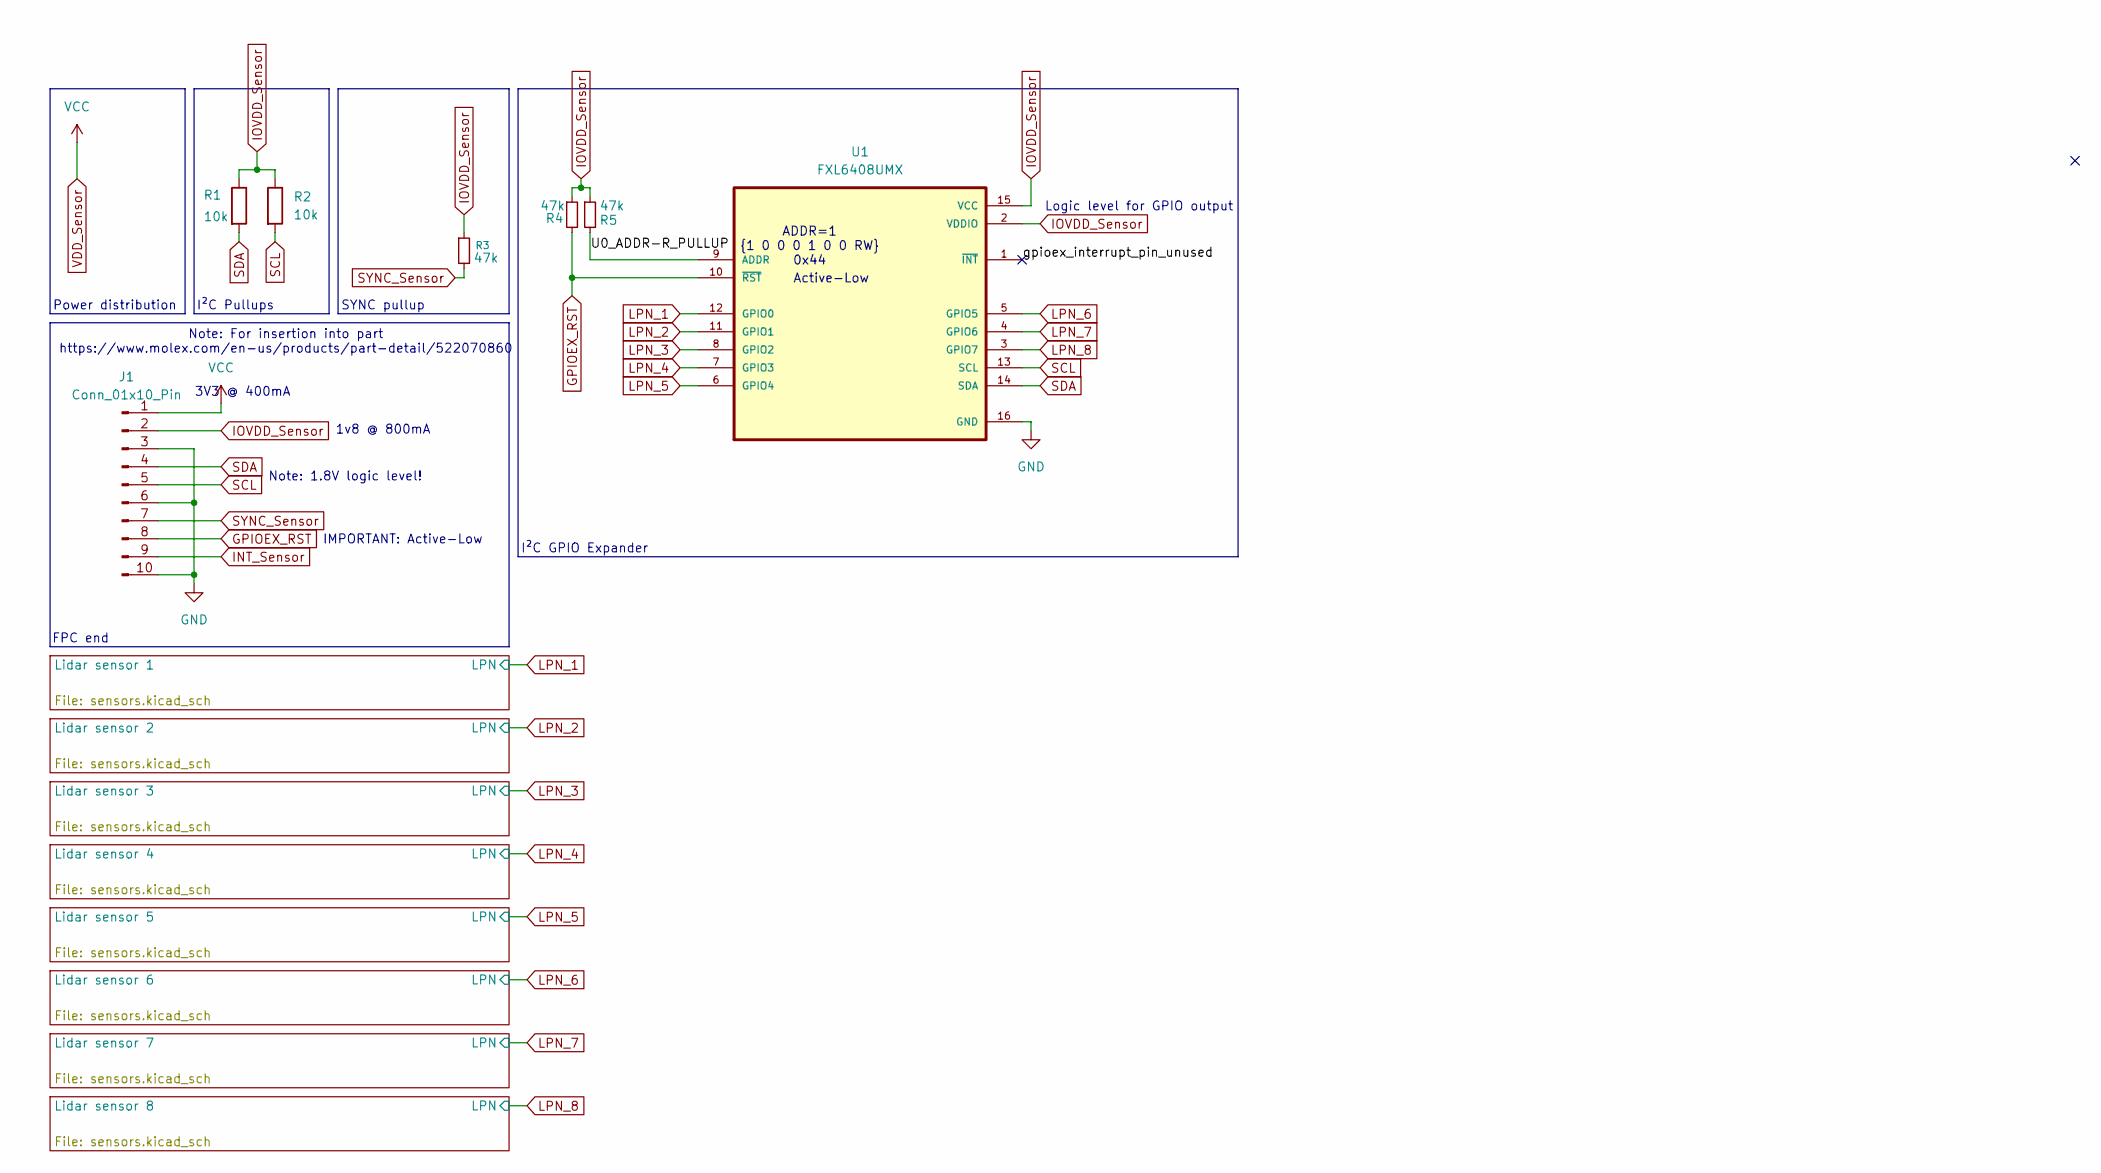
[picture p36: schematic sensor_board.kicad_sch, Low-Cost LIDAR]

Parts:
J1: Conn_01x10_Pin; Molex 10 Pin Flex 52207-1060
R1, R2: 10k; R_0603_1608Metric_Pad0.98x0.95mm_HandSolder
R3, R4, R5: 47k; R_0603_1608Metric_Pad0.98x0.95mm_HandSolder
U1: FXL6408UMX; QFN40P260X180X55-16N; PART_REV 1.0.0

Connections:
/U0_ADDR-R_PULLUP: R5.2, U1.9 (ADDR)
/gpioex_interrupt_pin_unused: U1.1 (~INT)
GND: J1.3, J1.6, J1.10, U1.16 (GND); also elsewhere on the board
GPIOEX_RST: J1.8, R4.2, U1.10 (~RST)
INT_Sensor: J1.9; also elsewhere on the board
IOVDD_Sensor: J1.2, R1.1, R2.1, R3.1, R4.1, R5.1, U1.2 (VDDIO), U1.15 (VCC); also elsewhere on the board
LPN_1: U1.12 (GPIO0); also elsewhere on the board
LPN_2: U1.11 (GPIO1); also elsewhere on the board
LPN_3: U1.8 (GPIO2); also elsewhere on the board
LPN_4: U1.7 (GPIO3); also elsewhere on the board
LPN_5: U1.6 (GPIO4); also elsewhere on the board
LPN_6: U1.5 (GPIO5); also elsewhere on the board
LPN_7: U1.4 (GPIO6); also elsewhere on the board
LPN_8: U1.3 (GPIO7); also elsewhere on the board
SCL: J1.5, R2.2, U1.13 (SCL); also elsewhere on the board
SDA: J1.4, R1.2, U1.14 (SDA); also elsewhere on the board
SYNC_Sensor: J1.7, R3.2; also elsewhere on the board
VDD_Sensor: J1.1; also elsewhere on the board

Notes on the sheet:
Logic level for GPIO output
Active-Low
Note: For insertion into part https://www.molex.com/en-us/products/part-detail/522070860
Note: 1.8V logic level!
I²C Pullups
IMPORTANT: Active-Low
ADDR=1 {1 0 0 0 1 0 0 RW} 0x44
Power distribution
SYNC pullup
FPC end
I²C GPIO Expander
1v8 @ 800mA
3V3 @ 400mA

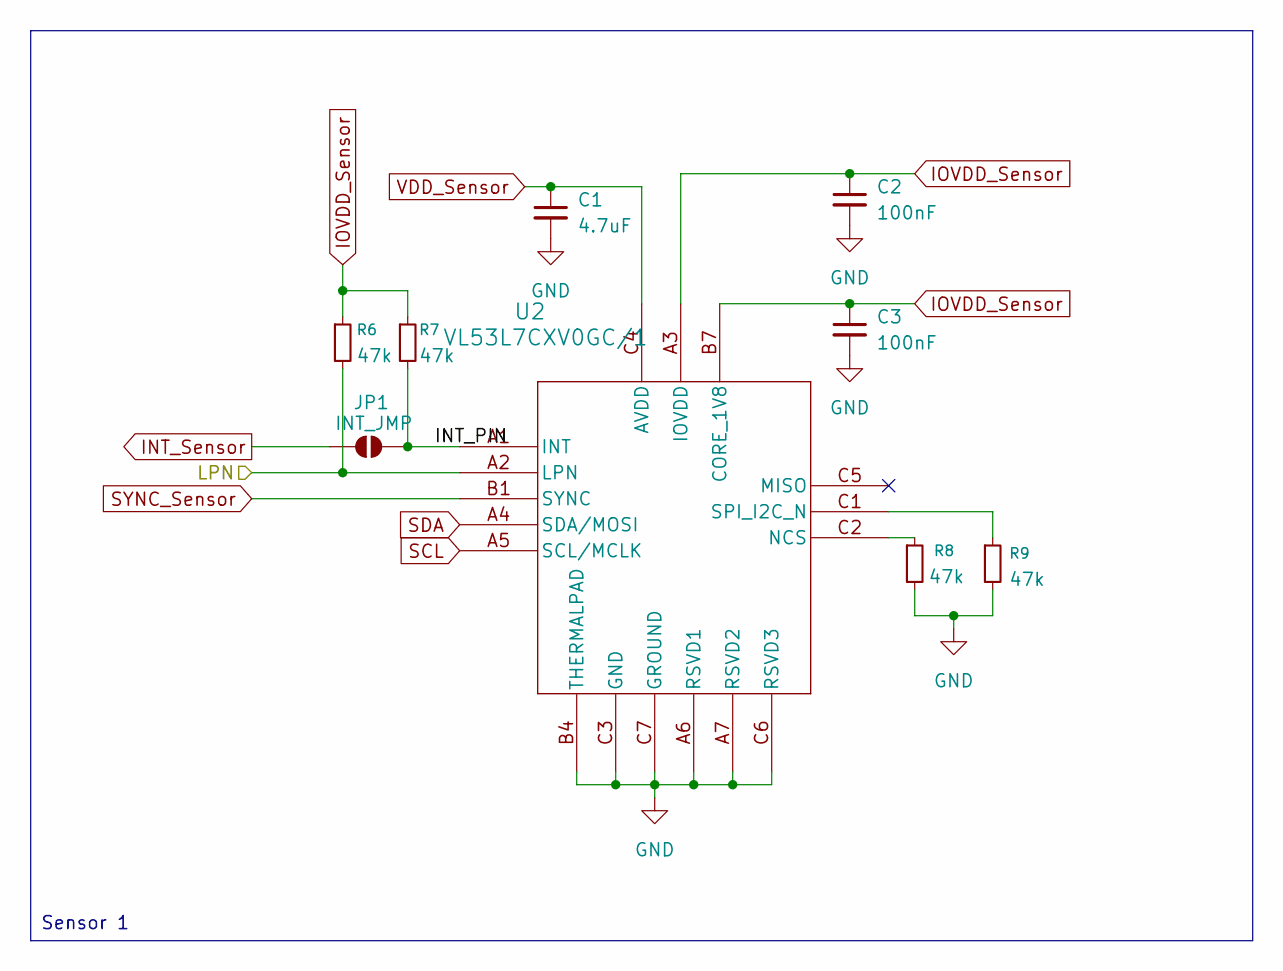
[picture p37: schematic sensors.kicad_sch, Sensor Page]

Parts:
C1: 4.7uF; C_0603_1608Metric_Pad1.08x0.95mm_HandSolder
C2, C3: 100nF; C_0603_1608Metric_Pad1.08x0.95mm_HandSolder
JP1: INT_JMP; C_0603_1608Metric_Pad1.08x0.95mm_HandSolder
R6, R7, R8, R9: 47k; R_0603_1608Metric_Pad0.98x0.95mm_HandSolder
U2: VL53L7CXV0GC/1; IC17_LGA16_STM

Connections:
/Lidar sensor 1/INT_PIN: JP1.2 (B), R7.2, U2.A1 (INT)
GND: C1.2, C2.2, C3.2, R8.2, R9.2, U2.A6 (RSVD1), U2.A7 (RSVD2), U2.B4 (THERMALPAD), U2.C3 (GND), U2.C6 (RSVD3), U2.C7 (GROUND); also elsewhere on the board
INT_Sensor: JP1.1 (A); also elsewhere on the board
IOVDD_Sensor: C2.1, C3.1, R6.1, R7.1, U2.A3 (IOVDD), U2.B7 (CORE_1V8); also elsewhere on the board
LPN_1: R6.2, U2.A2 (LPN); also elsewhere on the board
unnamed: R8.1, U2.C2 (NCS)
unnamed: R9.1, U2.C1 (SPI_I2C_N)
SCL: U2.A5 (SCL/MCLK); also elsewhere on the board
SDA: U2.A4 (SDA/MOSI); also elsewhere on the board
SYNC_Sensor: U2.B1 (SYNC); also elsewhere on the board
VDD_Sensor: C1.1, U2.C4 (AVDD); also elsewhere on the board

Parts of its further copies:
C4, C7, C10, C13, C16, C19, C22: 4.7uF; C_0603_1608Metric_Pad1.08x0.95mm_HandSolder
C5, C6, C8, C9, C11, C12, C14, C15, C17, C18, C20, C21, C23, C24: 100nF; C_0603_1608Metric_Pad1.08x0.95mm_HandSolder
JP2, JP3, JP4, JP5, JP6, JP7, JP8: INT_JMP; C_0603_1608Metric_Pad1.08x0.95mm_HandSolder
R10, R11, R12, R13, R14, R15, R16, R17, R18, R19, R20, R21, R22, R23, R24, R25, R26, R27, R28, R29, R30, R31, R32, R33, R34, R35, R36, R37: 47k; R_0603_1608Metric_Pad0.98x0.95mm_HandSolder
U3, U4, U5, U6, U7, U8, U9: VL53L7CXV0GC/1; IC17_LGA16_STM

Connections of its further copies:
/Lidar sensor 2/INT_PIN: JP2.2 (B), R11.2, U3.A1 (INT)
/Lidar sensor 3/INT_PIN: JP3.2 (B), R15.2, U4.A1 (INT)
/Lidar sensor 4/INT_PIN: JP4.2 (B), R19.2, U5.A1 (INT)
/Lidar sensor 5/INT_PIN: JP5.2 (B), R23.2, U6.A1 (INT)
/Lidar sensor 6/INT_PIN: JP6.2 (B), R27.2, U7.A1 (INT)
/Lidar sensor 7/INT_PIN: JP7.2 (B), R31.2, U8.A1 (INT)
/Lidar sensor 8/INT_PIN: JP8.2 (B), R35.2, U9.A1 (INT)
GND: C4.2, C5.2, C6.2, C7.2, C8.2, C9.2, C10.2, C11.2, C12.2, C13.2, C14.2, C15.2, C16.2, C17.2, C18.2, C19.2, C20.2, C21.2, C22.2, C23.2, C24.2, R12.2, R13.2, R16.2, R17.2, R20.2, R21.2, R24.2, R25.2, R28.2, R29.2, R32.2, R33.2, R36.2, R37.2, U3.A6 (RSVD1), U3.A7 (RSVD2), U3.B4 (THERMALPAD), U3.C3 (GND), U3.C6 (RSVD3), U3.C7 (GROUND), U4.A6 (RSVD1), U4.A7 (RSVD2), U4.B4 (THERMALPAD), U4.C3 (GND), U4.C6 (RSVD3), U4.C7 (GROUND), U5.A6 (RSVD1), U5.A7 (RSVD2), U5.B4 (THERMALPAD), U5.C3 (GND), U5.C6 (RSVD3), U5.C7 (GROUND), U6.A6 (RSVD1), U6.A7 (RSVD2), U6.B4 (THERMALPAD), U6.C3 (GND), U6.C6 (RSVD3), U6.C7 (GROUND), U7.A6 (RSVD1), U7.A7 (RSVD2), U7.B4 (THERMALPAD), U7.C3 (GND), U7.C6 (RSVD3), U7.C7 (GROUND), U8.A6 (RSVD1), U8.A7 (RSVD2), U8.B4 (THERMALPAD), U8.C3 (GND), U8.C6 (RSVD3), U8.C7 (GROUND), U9.A6 (RSVD1), U9.A7 (RSVD2), U9.B4 (THERMALPAD), U9.C3 (GND), U9.C6 (RSVD3), U9.C7 (GROUND); also elsewhere on the board
INT_Sensor: JP2.1 (A), JP3.1 (A), JP4.1 (A), JP5.1 (A), JP6.1 (A), JP7.1 (A), JP8.1 (A); also elsewhere on the board
IOVDD_Sensor: C5.1, C6.1, C8.1, C9.1, C11.1, C12.1, C14.1, C15.1, C17.1, C18.1, C20.1, C21.1, C23.1, C24.1, R10.1, R11.1, R14.1, R15.1, R18.1, R19.1, R22.1, R23.1, R26.1, R27.1, R30.1, R31.1, R34.1, R35.1, U3.A3 (IOVDD), U3.B7 (CORE_1V8), U4.A3 (IOVDD), U4.B7 (CORE_1V8), U5.A3 (IOVDD), U5.B7 (CORE_1V8), U6.A3 (IOVDD), U6.B7 (CORE_1V8), U7.A3 (IOVDD), U7.B7 (CORE_1V8), U8.A3 (IOVDD), U8.B7 (CORE_1V8), U9.A3 (IOVDD), U9.B7 (CORE_1V8); also elsewhere on the board
LPN_2: R10.2, U3.A2 (LPN); also elsewhere on the board
LPN_3: R14.2, U4.A2 (LPN); also elsewhere on the board
LPN_4: R18.2, U5.A2 (LPN); also elsewhere on the board
LPN_5: R22.2, U6.A2 (LPN); also elsewhere on the board
LPN_6: R26.2, U7.A2 (LPN); also elsewhere on the board
LPN_7: R30.2, U8.A2 (LPN); also elsewhere on the board
LPN_8: R34.2, U9.A2 (LPN); also elsewhere on the board
unnamed: R12.1, U3.C2 (NCS)
unnamed: R13.1, U3.C1 (SPI_I2C_N)
unnamed: R16.1, U4.C2 (NCS)
unnamed: R17.1, U4.C1 (SPI_I2C_N)
unnamed: R20.1, U5.C2 (NCS)
unnamed: R21.1, U5.C1 (SPI_I2C_N)
unnamed: R24.1, U6.C2 (NCS)
unnamed: R25.1, U6.C1 (SPI_I2C_N)
unnamed: R28.1, U7.C2 (NCS)
unnamed: R29.1, U7.C1 (SPI_I2C_N)
unnamed: R32.1, U8.C2 (NCS)
unnamed: R33.1, U8.C1 (SPI_I2C_N)
unnamed: R36.1, U9.C2 (NCS)
unnamed: R37.1, U9.C1 (SPI_I2C_N)
SCL: U3.A5 (SCL/MCLK), U4.A5 (SCL/MCLK), U5.A5 (SCL/MCLK), U6.A5 (SCL/MCLK), U7.A5 (SCL/MCLK), U8.A5 (SCL/MCLK), U9.A5 (SCL/MCLK); also elsewhere on the board
SDA: U3.A4 (SDA/MOSI), U4.A4 (SDA/MOSI), U5.A4 (SDA/MOSI), U6.A4 (SDA/MOSI), U7.A4 (SDA/MOSI), U8.A4 (SDA/MOSI), U9.A4 (SDA/MOSI); also elsewhere on the board
SYNC_Sensor: U3.B1 (SYNC), U4.B1 (SYNC), U5.B1 (SYNC), U6.B1 (SYNC), U7.B1 (SYNC), U8.B1 (SYNC), U9.B1 (SYNC); also elsewhere on the board
VDD_Sensor: C4.1, C7.1, C10.1, C13.1, C16.1, C19.1, C22.1, U3.C4 (AVDD), U4.C4 (AVDD), U5.C4 (AVDD), U6.C4 (AVDD), U7.C4 (AVDD), U8.C4 (AVDD), U9.C4 (AVDD); also elsewhere on the board

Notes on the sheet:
Sensor 1

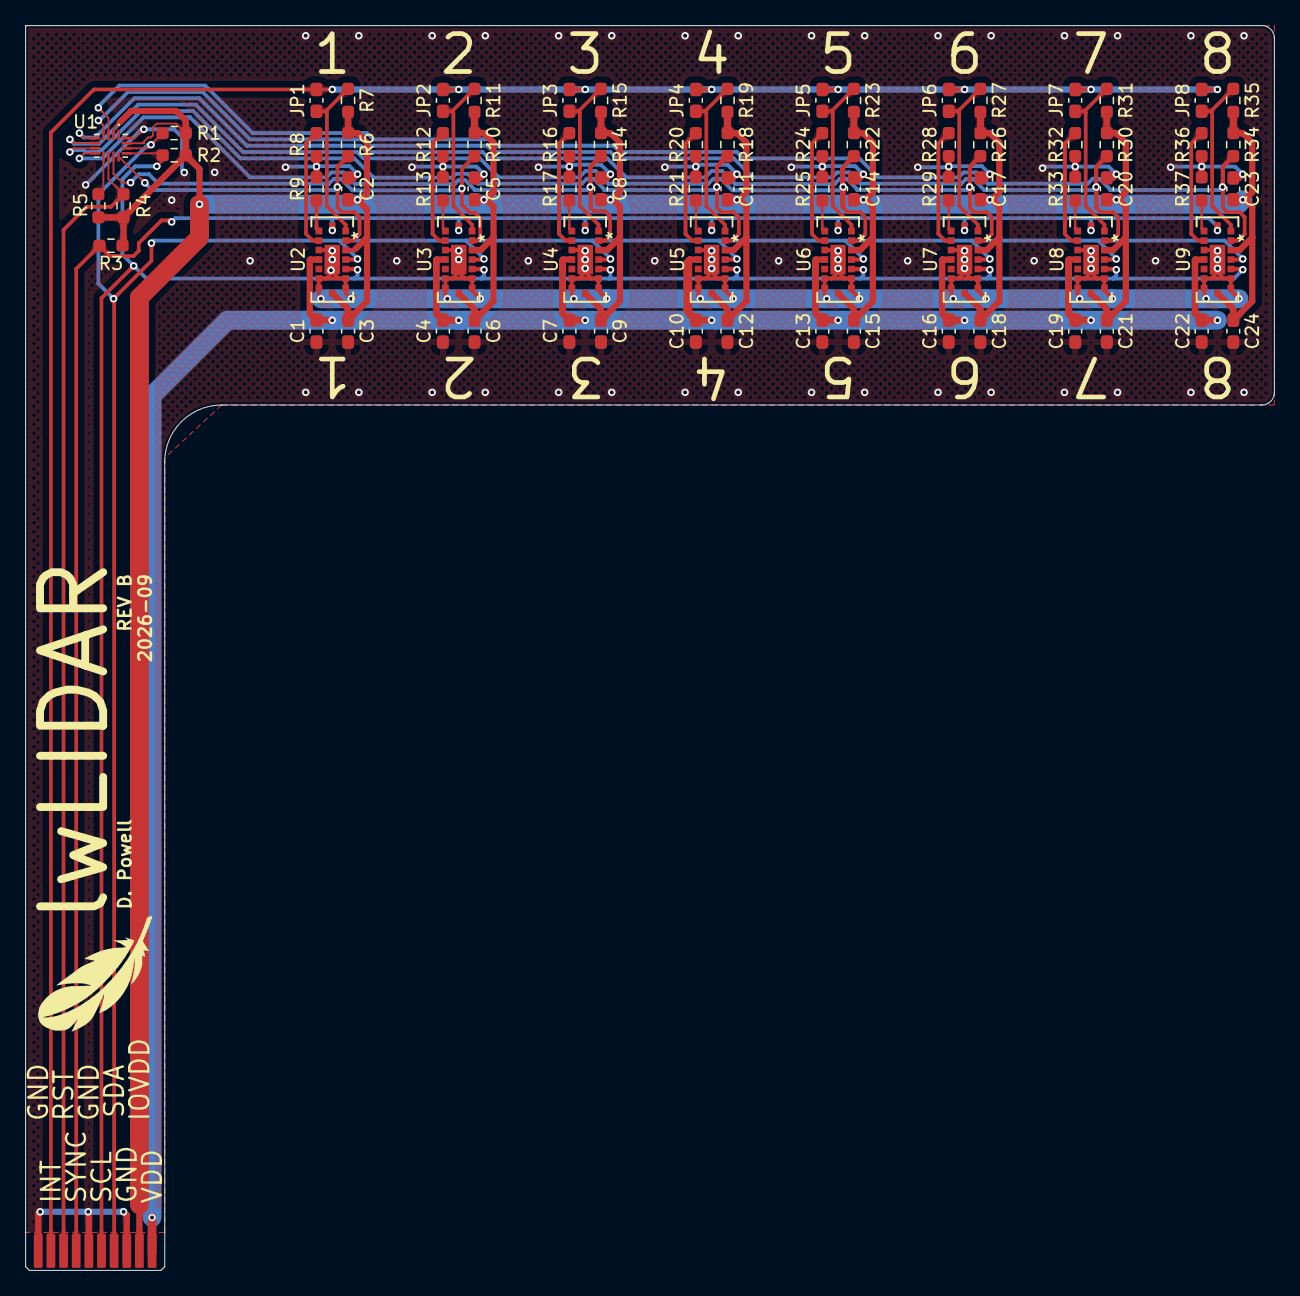
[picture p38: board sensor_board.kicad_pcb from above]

Board: 2 copper layers, 98.8 x 98.4 mm, 79 parts (0 on the bottom side), 41 nets.

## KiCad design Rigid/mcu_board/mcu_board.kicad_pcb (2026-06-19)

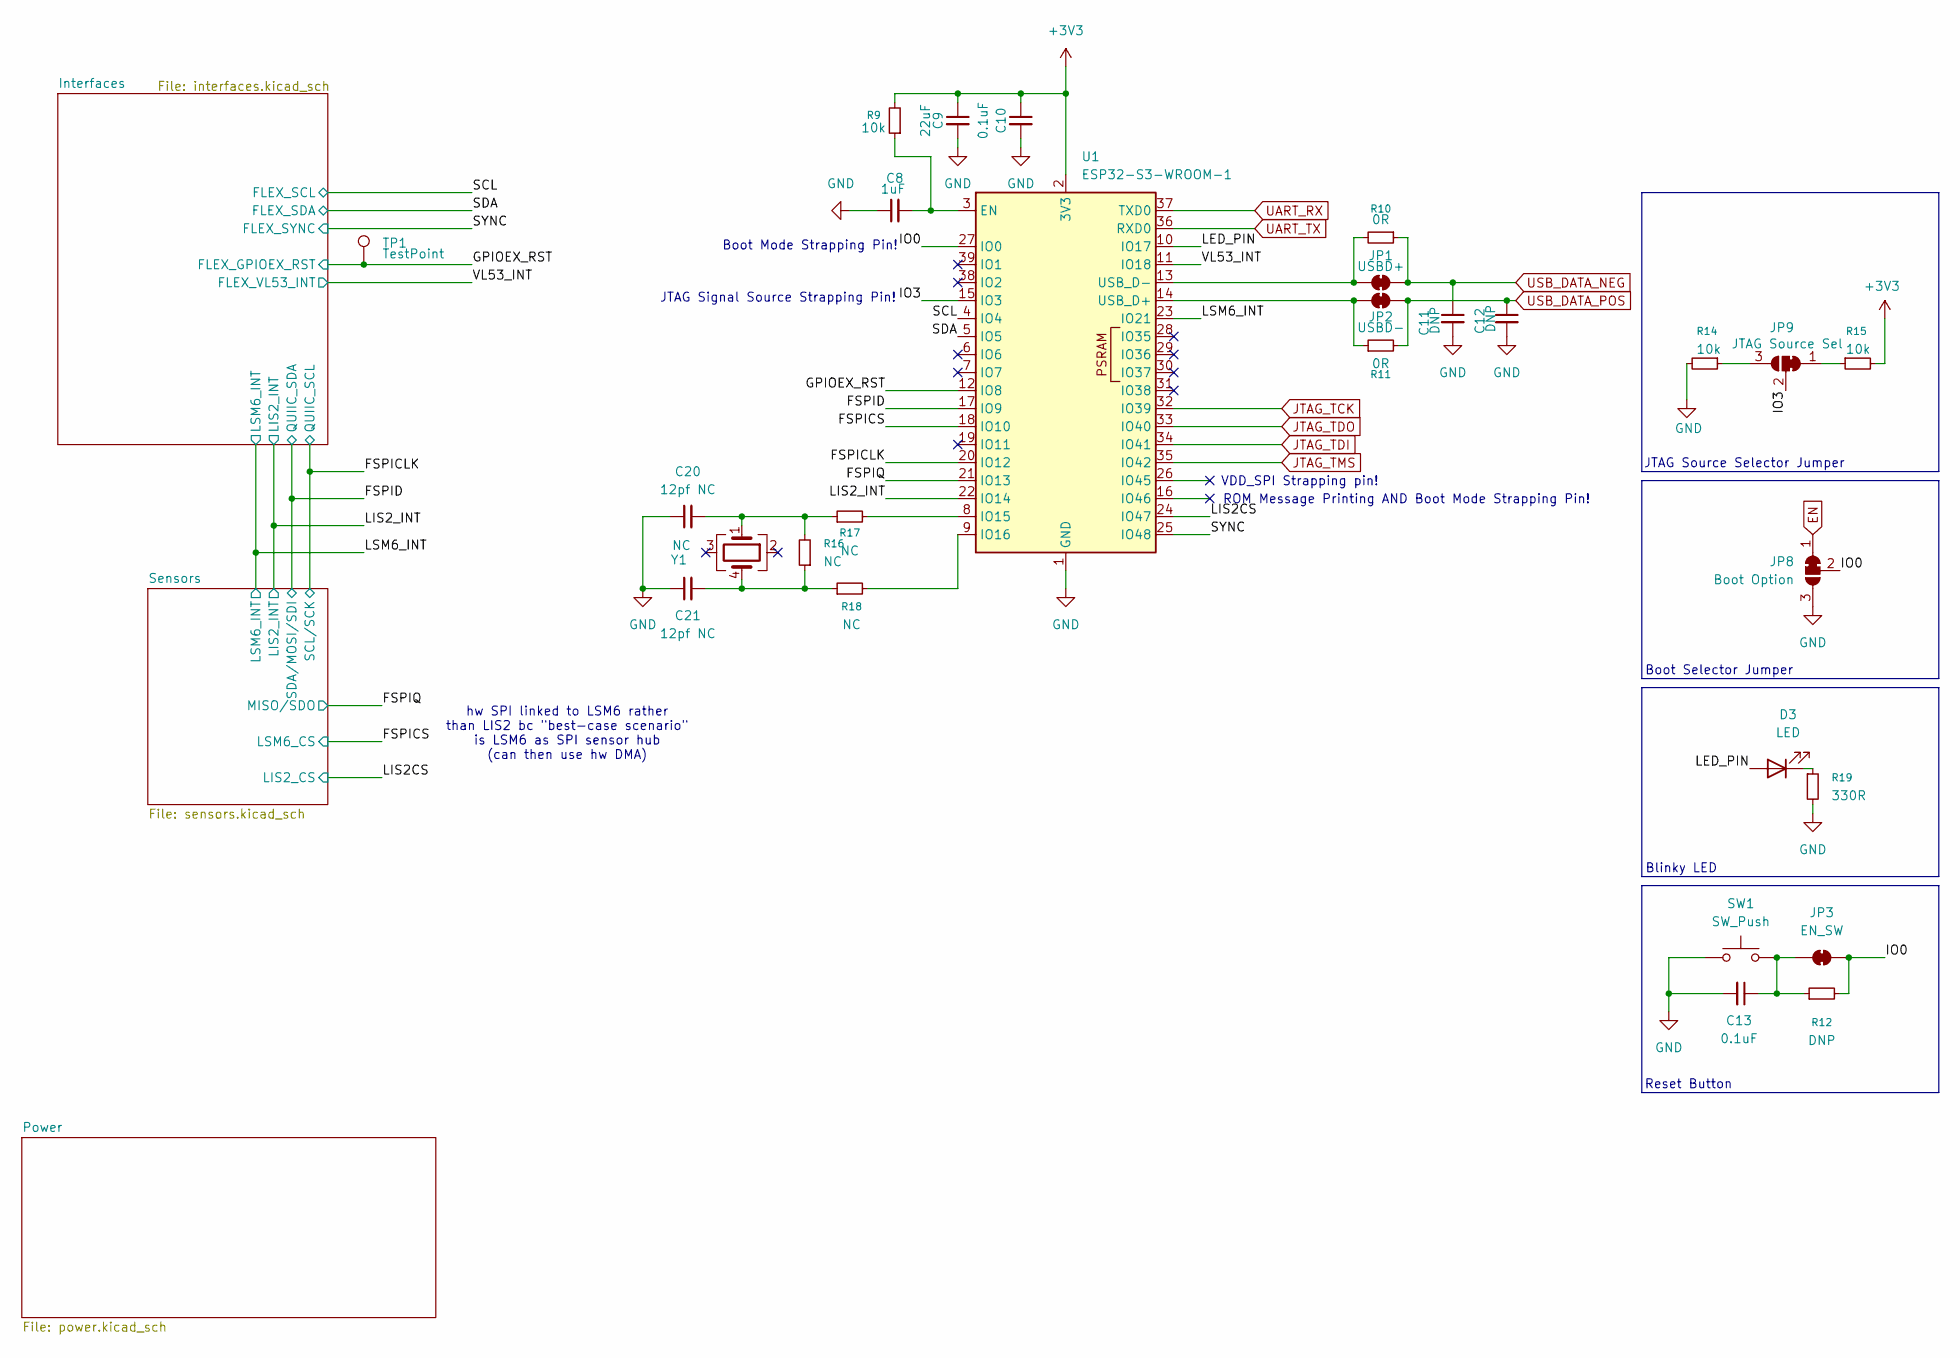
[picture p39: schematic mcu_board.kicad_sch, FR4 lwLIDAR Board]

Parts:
C8: 1uF; C_0603_1608Metric_Pad1.08x0.95mm_HandSolder
C9: 22uF; C_0603_1608Metric_Pad1.08x0.95mm_HandSolder
C10, C13: 0.1uF; C_0603_1608Metric_Pad1.08x0.95mm_HandSolder
C11, C12: DNP; C_0603_1608Metric_Pad1.08x0.95mm_HandSolder
C20, C21: 12pf NC; C_0603_1608Metric_Pad1.08x0.95mm_HandSolder
D3: LED; LED_0603_1608Metric_Pad1.05x0.95mm_HandSolder
JP1: USBD+; SolderJumper-2_P1.3mm_Bridged_RoundedPad1.0x1.5mm
JP2: USBD-; SolderJumper-2_P1.3mm_Bridged_RoundedPad1.0x1.5mm
JP3: EN_SW; SolderJumper-2_P1.3mm_Bridged2Bar_RoundedPad1.0x1.5mm
JP8: Boot Option; SolderJumper-3_P1.3mm_Bridged12_RoundedPad1.0x1.5mm
JP9: JTAG Source Sel; SolderJumper-3_P1.3mm_Bridged12_RoundedPad1.0x1.5mm
R9, R14, R15: 10k; R_0603_1608Metric_Pad0.98x0.95mm_HandSolder
R10, R11: 0R; R_0603_1608Metric_Pad0.98x0.95mm_HandSolder
R12: DNP; R_0603_1608Metric_Pad0.98x0.95mm_HandSolder
R16, R17, R18: NC; R_0603_1608Metric_Pad0.98x0.95mm_HandSolder
R19: 330R; R_0603_1608Metric_Pad0.98x0.95mm_HandSolder
SW1: SW_Push; SW_Push_1P1T_NO_CK_KMR2
TP1: TestPoint; TestPoint_Pad_D1.0mm
U1: ESP32-S3-WROOM-1
Y1: NC; Crystal_SMD_SeikoEpson_MC306-4Pin_8.0x3.2mm

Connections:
+3V3: C9.1, C10.1, R9.2, R15.2, U1.2 (3V3); also elsewhere on the board
/FSPICLK: U1.20 (IO12); also elsewhere on the board
/FSPICS: U1.18 (IO10); also elsewhere on the board
/FSPID: U1.17 (IO9); also elsewhere on the board
/FSPIQ: U1.21 (IO13); also elsewhere on the board
/GPIOEX_RST: TP1.1, U1.12 (IO8); also elsewhere on the board
/IO0: JP3.2 (B), JP8.2 (C), R12.2, U1.27 (IO0)
/IO3: JP9.2 (C), U1.15 (IO3)
/LED_PIN: D3.2 (A), U1.10 (IO17)
/LIS2CS: U1.24 (IO47); also elsewhere on the board
/LIS2_INT: U1.22 (IO14); also elsewhere on the board
/LSM6_INT: U1.23 (IO21); also elsewhere on the board
/SCL: U1.4 (IO4); also elsewhere on the board
/SDA: U1.5 (IO5); also elsewhere on the board
/SYNC: U1.25 (IO48); also elsewhere on the board
/VL53_INT: U1.11 (IO18); also elsewhere on the board
EN: JP8.1 (A); also elsewhere on the board
GND: C8.1, C9.2, C10.2, C11.2, C12.2, C13.2, C20.1, C21.1, JP8.3 (B), R14.2, R19.2, SW1.1, U1.1 (GND), U1.40 (GND), U1.41 (GND); also elsewhere on the board
JTAG_TCK: U1.32 (IO39); also elsewhere on the board
JTAG_TDI: U1.34 (IO41); also elsewhere on the board
JTAG_TDO: U1.33 (IO40); also elsewhere on the board
JTAG_TMS: U1.35 (IO42); also elsewhere on the board
unnamed: C20.2, R16.2, R17.1, Y1.1
unnamed: C21.2, R16.1, R18.1, Y1.4
unnamed: D3.1 (K), R19.1
unnamed: JP1.1 (A), R10.2, U1.13 (USB_D-)
unnamed: JP2.1 (A), R11.1, U1.14 (USB_D+)
unnamed: C13.1, JP3.1 (A), R12.1, SW1.2
unnamed: JP9.1 (A), R15.1
unnamed: JP9.3 (B), R14.1
unnamed: C8.2, R9.1, U1.3 (EN)
unnamed: R17.2, U1.8 (IO15)
unnamed: R18.2, U1.9 (IO16)
UART_RX: U1.37 (TXD0); also elsewhere on the board
UART_TX: U1.36 (RXD0); also elsewhere on the board
USB_DATA_NEG: C11.1, JP1.2 (B), R10.1; also elsewhere on the board
USB_DATA_POS: C12.1, JP2.2 (B), R11.2; also elsewhere on the board

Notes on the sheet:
ROM Message Printing AND Boot Mode Strapping Pin!
VDD_SPI Strapping pin!
Reset Button
JTAG Signal Source Strapping Pin!
hw SPI linked to LSM6 rather than LIS2 bc "best-case scenario" is LSM6 as SPI sensor hub (can then use hw DMA)
Boot Selector Jumper
JTAG Source Selector Jumper
Blinky LED
Boot Mode Strapping Pin!

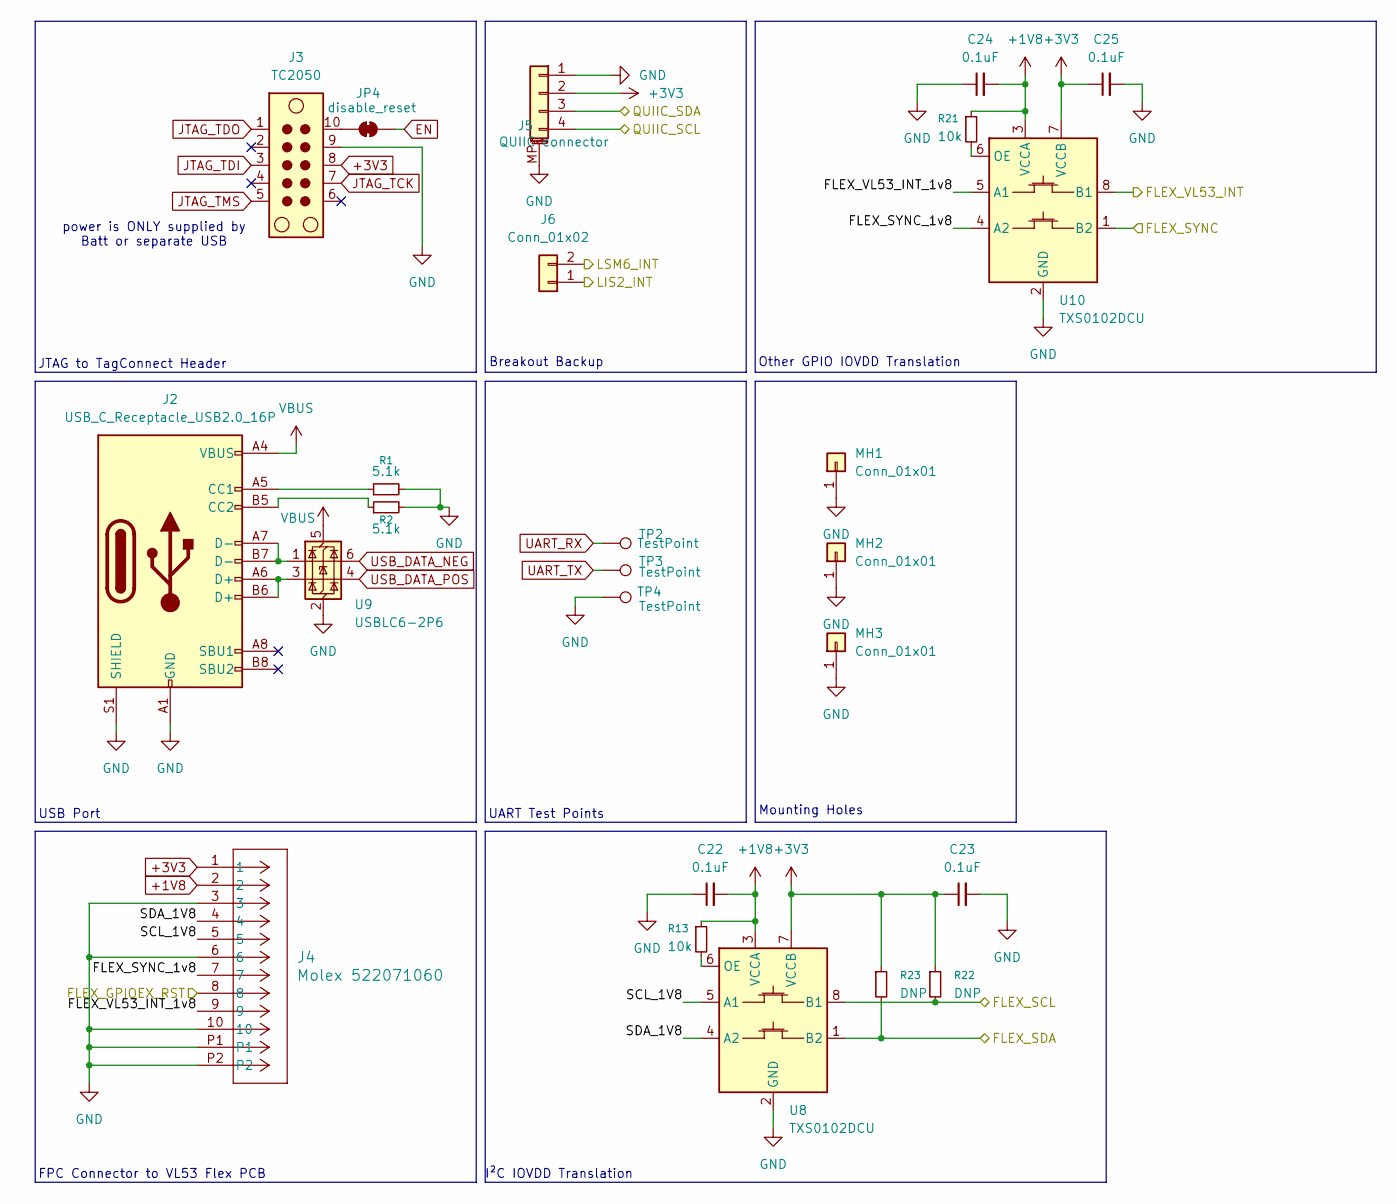
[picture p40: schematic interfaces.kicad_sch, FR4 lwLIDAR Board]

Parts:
C22, C23, C24, C25: 0.1uF; C_0603_1608Metric_Pad1.08x0.95mm_HandSolder
J2: USB_C_Receptacle_USB2.0_16P; USB_C_Receptacle_GCT_USB4105-xx-A_16P_TopMnt_Horizontal
J3: TC2050; Tag-Connect_TC2050-IDC-NL_2x05_P1.27mm_Vertical
J4: Molex 522071060; CON_522071060_MOL
J5: QUIIC connector; JST_SH_SM04B-SRSS-TB_1x04-1MP_P1.00mm_Horizontal
J6: Conn_01x02; PinHeader_1x02_P2.54mm_Vertical
JP4: disable_reset; SolderJumper-2_P1.3mm_Bridged_RoundedPad1.0x1.5mm
MH1, MH2, MH3: Conn_01x01; MountingHole_2.5mm_Pad_Via
R1, R2: 5.1k; R_0603_1608Metric_Pad0.98x0.95mm_HandSolder
R13, R21: 10k; R_0603_1608Metric_Pad0.98x0.95mm_HandSolder
R22, R23: DNP; R_0603_1608Metric_Pad0.98x0.95mm_HandSolder
TP2, TP3: TestPoint; TestPoint_Pad_D1.0mm
TP4: TestPoint; TestPoint_Pad_1.0x1.0mm
U8, U10: TXS0102DCU; VSSOP-8_2.3x2mm_P0.5mm
U9: USBLC6-2P6; SOT-666

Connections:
+1V8: C22.2, C24.2, J4.2, R13.1, R21.1, U8.3 (VCCA), U10.3 (VCCA); also elsewhere on the board
+3V3: C23.1, C25.1, J3.8, J4.1, J5.2, R22.1, R23.1, U8.7 (VCCB), U10.7 (VCCB); also elsewhere on the board
/FSPICLK: J5.4; also elsewhere on the board
/FSPID: J5.3; also elsewhere on the board
/GPIOEX_RST: J4.8; also elsewhere on the board
/Interfaces/FLEX_SYNC_1v8: J4.7, U10.4 (A2)
/Interfaces/FLEX_VL53_INT_1v8: J4.9, U10.5 (A1)
/Interfaces/SCL_1V8: J4.5, U8.5 (A1)
/Interfaces/SDA_1V8: J4.4, U8.4 (A2)
/LIS2_INT: J6.1; also elsewhere on the board
/LSM6_INT: J6.2; also elsewhere on the board
/SCL: R22.2, U8.8 (B1); also elsewhere on the board
/SDA: R23.2, U8.1 (B2); also elsewhere on the board
/SYNC: U10.1 (B2); also elsewhere on the board
/VL53_INT: U10.8 (B1); also elsewhere on the board
EN: JP4.1 (A); also elsewhere on the board
GND: C22.1, C23.2, C24.1, C25.2, J2.A1 (GND), J2.A12 (GND), J2.B1 (GND), J2.B12 (GND), J2.S1 (SHIELD), J3.9, J4.3, J4.6, J4.10, J4.P1, J4.P2, J5.1, J5.MP (MountPin), MH1.1, MH2.1, MH3.1, R1.2, R2.2, TP4.1, U8.2 (GND), U9.2 (GND), U10.2 (GND); also elsewhere on the board
JTAG_TCK: J3.7; also elsewhere on the board
JTAG_TDI: J3.3; also elsewhere on the board
JTAG_TDO: J3.1; also elsewhere on the board
JTAG_TMS: J3.5; also elsewhere on the board
unnamed: J2.A5 (CC1), R1.1
unnamed: J2.B5 (CC2), R2.1
unnamed: J2.A6 (D+), J2.B6 (D+), U9.3 (I/O2)
unnamed: J2.A7 (D-), J2.B7 (D-), U9.1 (I/O1)
unnamed: J3.10, JP4.2 (B)
unnamed: R13.2, U8.6 (OE)
unnamed: R21.2, U10.6 (OE)
USB_DATA_NEG: U9.6 (I/O1); also elsewhere on the board
USB_DATA_POS: U9.4 (I/O2); also elsewhere on the board
VBUS: J2.A4 (VBUS), J2.A9 (VBUS), J2.B4 (VBUS), J2.B9 (VBUS), U9.5 (VBUS); also elsewhere on the board

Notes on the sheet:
JTAG to TagConnect Header
Other GPIO IOVDD Translation
USB Port
FPC Connector to VL53 Flex PCB
power is ONLY supplied by Batt or separate USB
Mounting Holes
Breakout Backup
I²C IOVDD Translation
UART Test Points

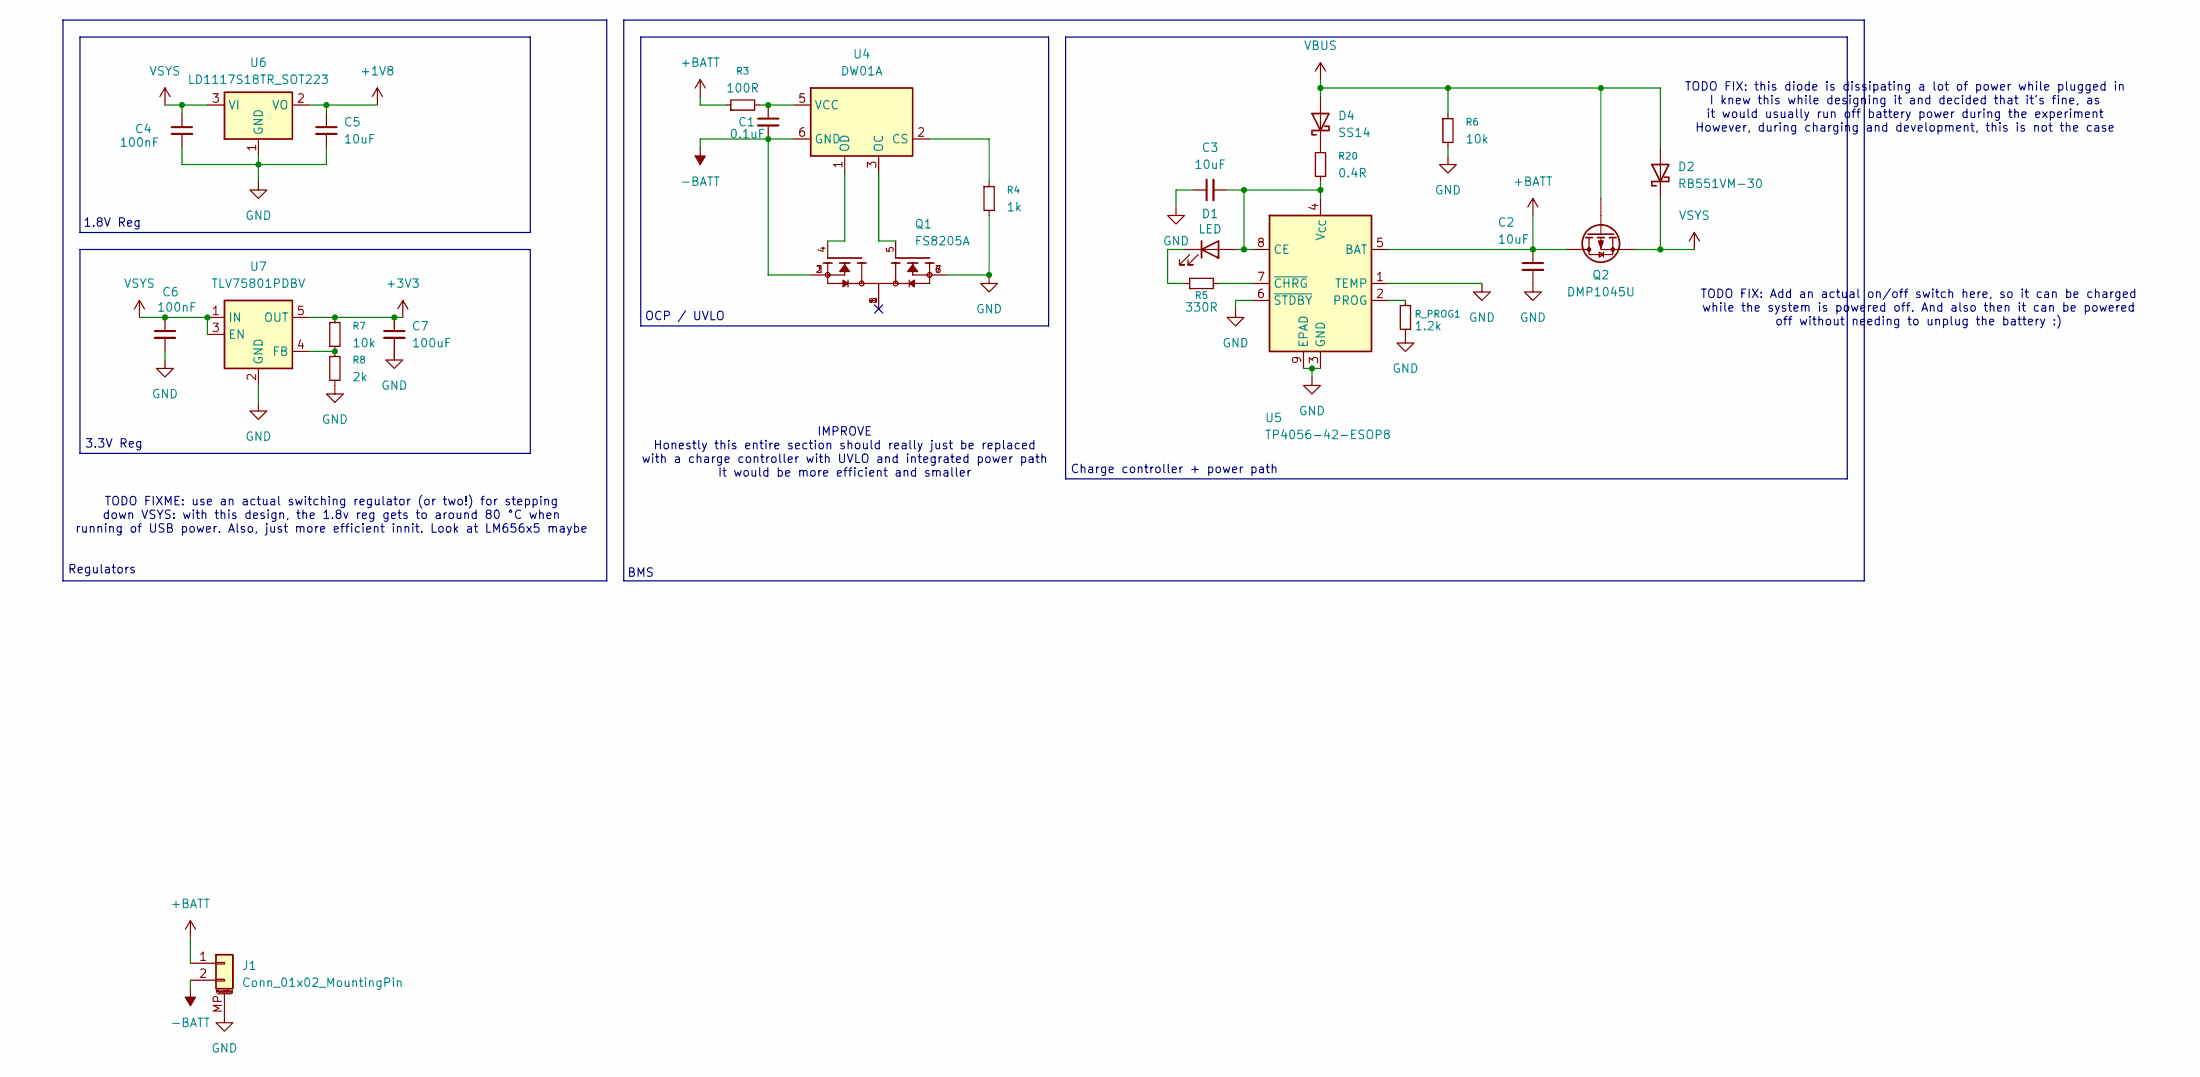
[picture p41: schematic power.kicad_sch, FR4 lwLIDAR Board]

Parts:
C1: 0.1uF; C_0603_1608Metric_Pad1.08x0.95mm_HandSolder
C2, C3, C5: 10uF; C_0603_1608Metric_Pad1.08x0.95mm_HandSolder
C4, C6: 100nF; C_0603_1608Metric_Pad1.08x0.95mm_HandSolder
C7: 100uF; C_0603_1608Metric_Pad1.08x0.95mm_HandSolder
D1: LED; LED_0603_1608Metric_Pad1.05x0.95mm_HandSolder
D2: RB551VM-30; DIO_RB500V_ROM
D4: SS14; DIOM5227X270N
J1: Conn_01x02_MountingPin; JST_PH_S2B-PH-SM4-TB_1x02-1MP_P2.00mm_Horizontal
Q1: FS8205A; SOP65P640X120-8N; PARTREV 1.7
Q2: DMP1045U; TSOT-23
R3: 100R; R_0603_1608Metric_Pad0.98x0.95mm_HandSolder
R4: 1k; R_0603_1608Metric_Pad0.98x0.95mm_HandSolder
R5: 330R; R_0603_1608Metric_Pad0.98x0.95mm_HandSolder
R6, R7: 10k; R_0603_1608Metric_Pad0.98x0.95mm_HandSolder
R8: 2k; R_0603_1608Metric_Pad0.98x0.95mm_HandSolder
R20: 0.4R; R_0603_1608Metric_Pad0.98x0.95mm_HandSolder
R_PROG1: 1.2k; R_0603_1608Metric_Pad0.98x0.95mm_HandSolder
U4: DW01A; SOT-23-6
U5: TP4056-42-ESOP8; SOIC-8-1EP_3.9x4.9mm_P1.27mm_EP2.41x3.3mm_ThermalVias
U6: LD1117S18TR_SOT223; SOT-223-3_TabPin2
U7: TLV75801PDBV; SOT-23-5

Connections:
+1V8: C5.1, U6.2 (VO); also elsewhere on the board
+3V3: C7.1, R7.1, U7.5 (OUT); also elsewhere on the board
+BATT: C2.1, J1.1, Q2.D, R3.1, U5.5 (BAT)
-BATT: C1.2, J1.2, Q1.2, Q1.3, U4.6 (GND)
GND: C2.2, C3.1, C4.2, C5.2, C6.2, C7.2, J1.MP (MountPin), Q1.6, Q1.7, R4.2, R6.2, R8.2, R_PROG1.2, U5.1 (TEMP), U5.3 (GND), U5.6 (~STDBY), U5.9 (EPAD), U6.1 (GND), U7.2 (GND); also elsewhere on the board
unnamed: C3.2, D1.2 (A), R20.2, U5.4 (V_{CC}), U5.8 (CE)
unnamed: D1.1 (K), R5.1
unnamed: D4.1 (K), R20.1
unnamed: R4.1, U4.2 (CS)
unnamed: Q1.5, U4.3 (OC)
unnamed: Q1.4, U4.1 (OD)
unnamed: C1.1, R3.2, U4.5 (VCC)
unnamed: R_PROG1.1, U5.2 (PROG)
unnamed: R5.2, U5.7 (~CHRG)
unnamed: R7.2, R8.1, U7.4 (FB)
VBUS: D2.2 (A), D4.2 (A), Q2.G, R6.1; also elsewhere on the board
VSYS: C4.1, C6.1, D2.1 (K), Q2.S, U6.3 (VI), U7.1 (IN), U7.3 (EN)

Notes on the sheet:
IMPROVE Honestly this entire section should really just be replaced with a charge controller with UVLO and integrated power path It would be more efficient and smaller
TODO FIX: Add an actual on/off switch here, so it can be charged while the system is powered off. And also then it can be powered off without needing to unplug the battery :)
3.3V Reg
OCP / UVLO
1.8V Reg
Regulators
TODO FIX: this diode is dissipating a lot of power while plugged in I knew this while designing it and decided that it's fine, as it would usually run off battery power during the experiment However, during charging and development, this is not the case
BMS
TODO FIXME: use an actual switching regulator (or two!) for stepping down VSYS: with this design, the 1.8v reg gets to around 80 °C when running of USB power. Also, just more efficient innit. Look at LM656x5 maybe
Charge controller + power path

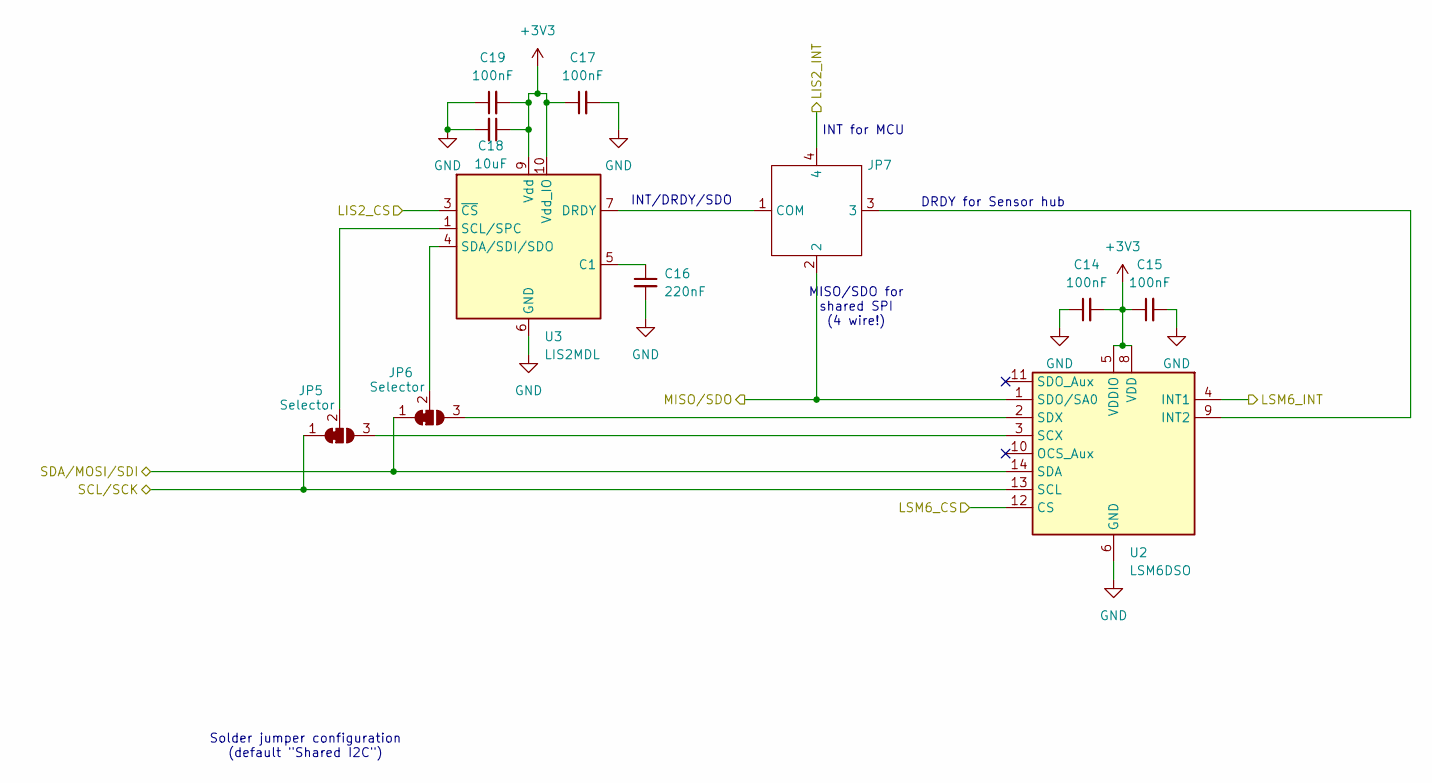
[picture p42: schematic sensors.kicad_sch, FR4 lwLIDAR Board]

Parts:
C14, C15, C17, C19: 100nF; C_0603_1608Metric_Pad1.08x0.95mm_HandSolder
C16: 220nF; C_0603_1608Metric_Pad1.08x0.95mm_HandSolder
C18: 10uF; C_0603_1608Metric_Pad1.08x0.95mm_HandSolder
JP5, JP6: Selector; SolderJumper-3_P1.3mm_Bridged12_RoundedPad1.0x1.5mm_NumberL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
JP7: 3waysel_default_4
U2: LSM6DSO; LGA-14_3x2.5mm_P0.5mm_LayoutBorder3x4y
U3: LIS2MDL; LGA-12_2x2mm_P0.5mm

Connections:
+3V3: C14.2, C15.1, C17.1, C18.1, C19.2, U2.5 (VDDIO), U2.8 (VDD), U3.9 (Vdd), U3.10 (Vdd_IO); also elsewhere on the board
/FSPICLK: JP5.1 (A), U2.13 (SCL); also elsewhere on the board
/FSPICS: U2.12 (CS); also elsewhere on the board
/FSPID: JP6.1 (A), U2.14 (SDA); also elsewhere on the board
/FSPIQ: JP7.2, U2.1 (SDO/SA0); also elsewhere on the board
/LIS2CS: U3.3 (~CS); also elsewhere on the board
/LIS2_INT: JP7.4; also elsewhere on the board
/LSM6_INT: U2.4 (INT1); also elsewhere on the board
GND: C14.1, C15.2, C16.2, C17.2, C18.2, C19.1, U2.6 (GND), U2.7 (GND), U3.6 (GND), U3.8 (GND); also elsewhere on the board
unnamed: JP5.3 (B), U2.3 (SCX)
unnamed: JP5.2 (C), U3.1 (SCL/SPC)
unnamed: JP6.3 (B), U2.2 (SDX)
unnamed: JP6.2 (C), U3.4 (SDA/SDI/SDO)
unnamed: JP7.1 (COM), U3.7 (DRDY)
unnamed: JP7.3, U2.9 (INT2)
unnamed: C16.1, U3.5 (C1)

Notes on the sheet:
MISO/SDO for shared SPI (4 wire!)
INT for MCU
DRDY for Sensor hub
Solder jumper configuration (default "Shared I2C")
INT/DRDY/SDO

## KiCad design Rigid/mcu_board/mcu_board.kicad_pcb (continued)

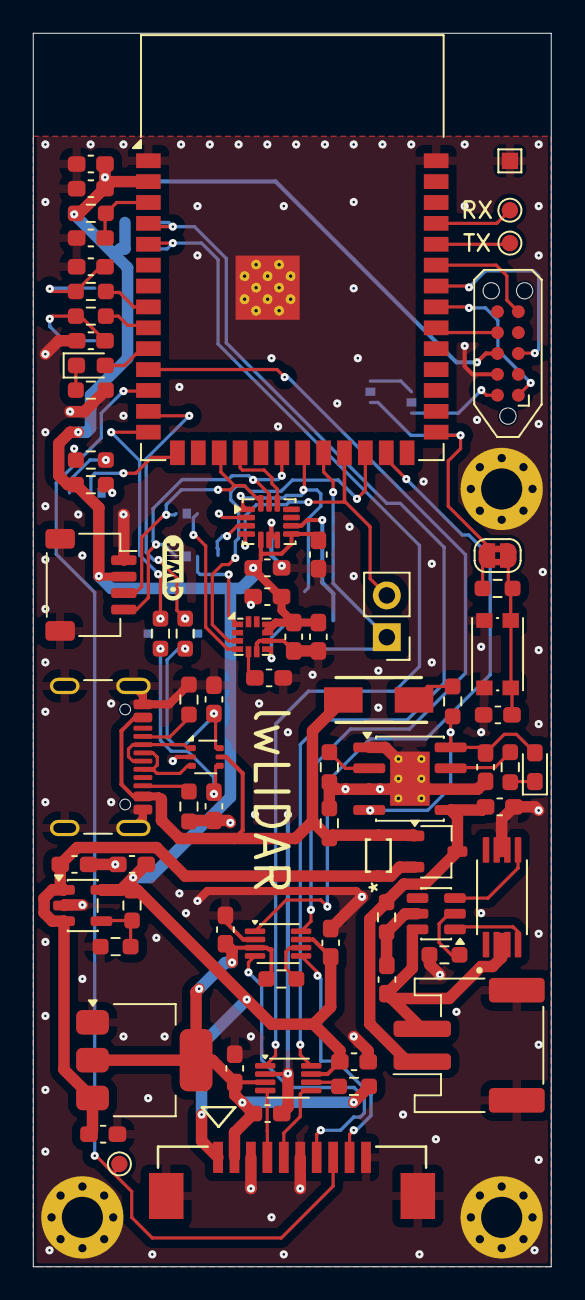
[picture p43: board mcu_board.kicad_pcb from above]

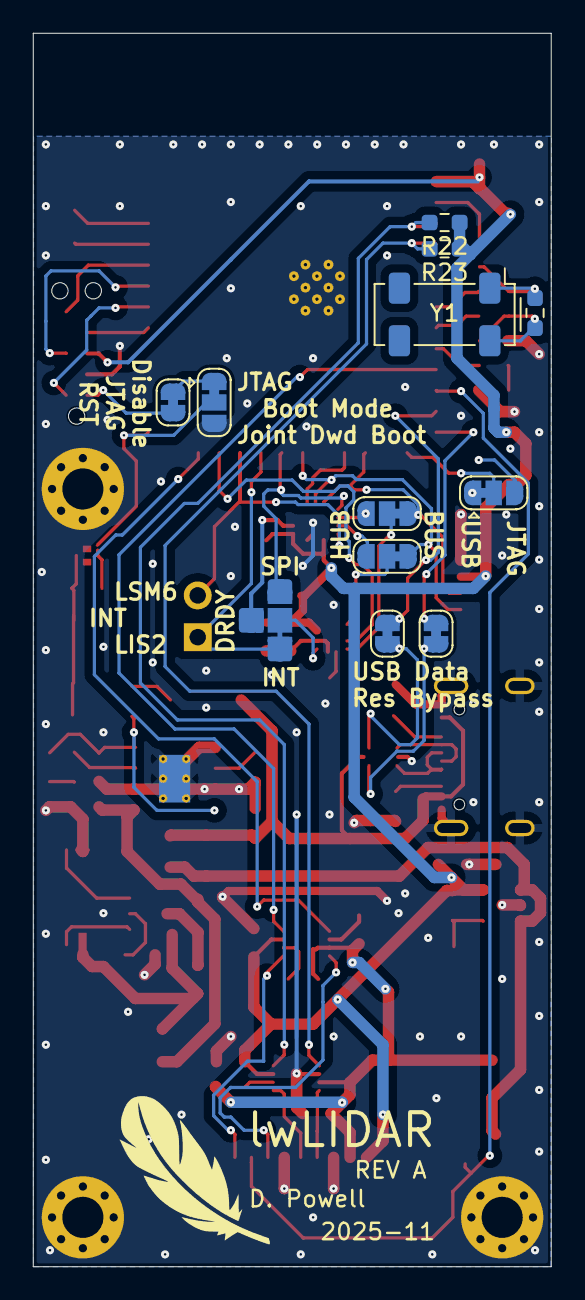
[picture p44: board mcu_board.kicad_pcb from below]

Board: 2 copper layers, 31.5 x 75.0 mm, 89 parts (12 on the bottom side), 70 nets.

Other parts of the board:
RX: TestPoint; TestPoint_Pad_D1.0mm
TX: TestPoint; TestPoint_Pad_D1.0mm

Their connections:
UART_RX: RX.1; also elsewhere on the board
UART_TX: TX.1; also elsewhere on the board

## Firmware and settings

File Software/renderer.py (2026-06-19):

import numpy as np
import quaternion
import time
import math
import viser
import serial
import socket
import threading
from datetime import datetime

from zeroconf import IPVersion, ServiceInfo, Zeroconf

from geom import ZoneAngles, compute_zone_angles

# Class for "old" usb-serial-based protocol
class serialParser:
    def __init__(self, port, baud):
        self.port = port
        self.baud = baud
        self._thread: threading.Thread | None = None
        self._running=False
        self._data_lock = threading.Lock() 
        self._distances=[]
        for i in range(0, 8):
            self._distances.append([])
            for j in range(0, 64):
                self._distances[i].append(0)

    def get_distances(self, sensor_num):
        with self._data_lock:
            return self._distances[sensor_num].copy()
    def connect(self):
        print(f"Connecting to {self.port} @ {self.baud} baud")
        self.serial = serial.Serial(port=self.port, baudrate=self.baud, timeout=1) 
        time.sleep(2)
        self.serial.reset_input_buffer()
    def start(self):
        self._running=True
        self._thread= threading.Thread(target=self._read_loop, daemon=True)
        self._thread.start()
    def stop(self):
        self._running=False
        if self.serial:
            self.serial.close()
        if self._thread:
            self._thread.join(timeout=1)
            self._thread=None
    def _read_loop(self):
        while self._running:
            try:
                line = self.serial.readline().decode("utf-8", errors="ignore").strip()
                if line.startswith("<> "):
                    l = line.split(" ")
                    snum = int(l[1])
                    print(snum, end=" ")
                    for m in range(2, len(l)):
                        self._distances[snum][m-2] = int(l[m])
                else:
                    print(f"\nesp> {line}");
            except:
                pass

# class for final network-based protocol (literally just a TCP port)
class networkParser:
    def __init__(self, port):
        self.sock = socket.socket()
        self.port = port
        self._thread: threading.Thread | None = None
        self._running=False
        self._data_lock = threading.Lock() 
        self._distances=[]
        self._buffer=""
        self._file=""
        self._dbgdata = {
                "lsm6_temp": -1,
                "lis2_temp": -1,
                "esp_temp": -1
                }
        for i in range(0, 8):
            self._distances.append([])
            for j in range(0, 64):
                self._distances[i].append(0)
    # From  https://stackoverflow.com/a/28950776
    # The tricky part here is that getting localhost's IP address
    # returns 127.0.0.1 (which is, by definition, correct)
    # However, I care about what my 'local' IP address is from
    # the perspective of other devices behind the same NAT as this machine
    # So, we have to do this hack-ish solution.
    # This will only work if the esp32 and this program are running on the same
    # "third party" network. If this program is running on a laptop hotspot, this
    # solution will probably break, as this function would return the IP address 
    # of the interface used to connect to the internet, while the esp32 would be on
    # a different subnet created by the wifi hotspot driver
    def _get_ip(self):
        s = socket.socket(socket.AF_INET, socket.SOCK_DGRAM)
        s.settimeout(0)
        try:
            # doesn't even have to be reachable
            s.connect(('10.254.254.254', 1))
            IP = s.getsockname()[0]
        except Exception:
            IP = '127.0.0.1'
        finally:
            s.close()
        return IP
    def get_distances(self, sensor_num):
        with self._data_lock:
            return self._distances[sensor_num].copy()
    def getDbg(self):
        with self._data_lock:
            return self._dbgdata
    def start(self):
        self._running=True
        self._thread= threading.Thread(target=self._read_loop, daemon=True)
        self._thread.start()
    def stop(self):
        self._running=False
        if self._thread:
            self._thread.join(timeout=1)
            self._thread=None
    def _handlePacket(self, packet):
        #print(packet)
        if packet.startswith("<>"):
            parts = packet.strip().split(" ")
            if parts[1] == "S":
                print(f"@{parts[2]}: FPS: {1/(int(parts[3])/1000000)}")
            # Check if sensor num
            elif parts[1] in ["0", "1", "2", "3", "4", "5", "6", "7"]:
                snum = int(parts[1]) #we need to go from Firmwares sensor (0-7) to visers sensors (1-8)
                with self._data_lock:
                    for m in range(3, len(parts)):
                        val = int(parts[m])
                        self._distances[snum][m-3] = val
                #print(f"@{parts[2]}: Sensor {snum}")
                #print("Failed to parse sensor packet")
            elif parts[1] == "A":
                # Accelerometer message
                pass
            elif parts[1] == "G":
                # Gyro message
                pass
            elif parts[1] == "M":
                # Magnetometer message
                pass
            elif parts[1] == "T":
                #Temperature message
                with self._data_lock:
                    self._dbgdata["lsm6_temp"] = float(parts[3])
            else:
                print(f"Got unknown packet type {parts[1]}")
        else:
            print(f"invalid packet: {packet}")
    def _handleUpdateBuffer(self, data):
        append = data.decode("utf8")
        if "\n" in append:
            inbetween = append.split("\n")
            self._buffer+=inbetween[0]
            self._handlePacket(self._buffer)
            self._buffer=inbetween[1]
        else:
            self._buffer+=append
    def _read_loop(self):
        print("Registering mDNS service")
        info = ServiceInfo(
            "_lwLIDAR._tcp.local.",
            "_Offloader._lwLIDAR._tcp.local.",
            addresses=[self._get_ip()],
            port=3133,
            #properties=desc,
            server="lwLIDAR_offload.local.",
        )
        zeroconf = Zeroconf(ip_version=IPVersion.All)
        zeroconf.register_service(info)

        bind_failed = True
        while bind_failed:
            try:
                self.sock.bind(('0.0.0.0', 3133))
                self.sock.listen(0)
                break
            except OSError:
                print("Address still in use. Waiting 10s")
                time.sleep(10)

        while self._running:
            filename = datetime.now().strftime("test-%Y-%m-%d_%H_%M_%S.log")
            with open(filename, "a") as self._file:
                print(f"Writing sensor data to: {filename}");
                while self._running:
                    try:
                        print("Waiting for connection")
                        #self.sock.settimeout(3)
                        client, addr = self.sock.accept()
                        print("Accept connection")
                        while self._running:
                            content = client.recv(128)
                            txt = content.decode("utf-8");
                            #print(txt, end="")
                            self._file.write(txt)
                            # NOTE: this is not ideal for performance (in theory), but in practice I have
                            # so much file write bandwidth on my laptop that I'd much rather be able to tail
                            # the logfile and see "live" updates than care abour file IO efficiency
                            self._file.flush()
                            if len(content) == 0:
                                    break
                            else:
                                self._handleUpdateBuffer(content)
                    except TimeoutError:
                        print("Socket connection timed out")
                    finally:
                        self.sock.close()
        print("Closing socket")
        self.sock.close()
            


# "test pattern" for me to check if sensor frames are correct
def get_sample_distances(sensor_num):
    a = [
            900, 100, 100, 100, 100, 100, 100, 100,
            100, 900, 100, 100, 100, 100, 100, 100,
            100, 100, 900, 100, 100, 100, 100, 100,
            100, 100, 100, 900, 100, 100, 100, 100,
            100, 100, 100, 100, 900, 100, 100, 100,
            100, 100, 100, 100, 100, 900, 100, 100,
            100, 100, 100, 100, 100, 100, 900, 100,
            100, 100, 100, 100, 100, 100, 100, 900
        ]
    return a


# function to take array of points and output part of point cloud
def gen_points(server, zone_angles, distances, sensor_num):
    #TODO make transformation matrix to apply to points at end of calculation
    #TODO for each point in 2d array calculate position relative to the sensor origin from the lookup table
    min_range = 20 / 1000
    max_range = 4000 / 1000
    
    rays = np.zeros((64, 2, 3))
    points = np.zeros((64, 3))
    for i in range(64):
        # Use ST lookup ray directions (already normalized)
        dir_x = zone_angles.st_ray_dir_x[i]
        dir_y = zone_angles.st_ray_dir_y[i]
        dir_z = zone_angles.st_ray_dir_z[i]
        # Scale to match tangent-style (z=1 convention)
        if dir_z > 0:
            dir_x = dir_x / dir_z
            dir_y = dir_y / dir_z
            dir_z = 1.0

        # Use measured distance if provided and valid, otherwise max range
        if distances is not None and distances[i] >= 20:
            end_range = distances[i] / 1000
        else:
            # Because we're using negative numbers for invalid measurement return codes.
            end_range = 0
        start = np.array([
            min_range * dir_x,
            min_range * dir_y,
            min_range * dir_z,
        ], dtype=np.float32)
        end = np.array([
            end_range * dir_x,
            end_range * dir_y,
            end_range * dir_z,
        ], dtype=np.float32)
        rays[i] = [start, end]
        points[i] = end

    npdistances = np.array(distances)
    normalised_dists = (npdistances - 20) / (3500-20)
    colours = np.zeros((64, 3), dtype=np.uint8);
    colours[:, 0] = ((1-normalised_dists) * 255).astype(np.uint8)
    colours[:, 1] = (normalised_dists * 255).astype(np.uint8)


    ray = server.scene.add_line_segments(
        f"/sensors/{sensor_num}/rays",
        points=rays,
        colors=(100, 150, 255),
        visible=False
    )
    pcloud = server.scene.add_point_cloud(
        f"/sensors/{sensor_num}/points",
        points=points,
        colors=colours,#(0, 255, 0),
        point_size=0.03,
        point_shape="circle"
    )


#Render sensor data
def process_frame(server, zone_angles, sport, lsm6_temp, lis2_temp, esp_temp):
    #get 8 sensors of data from parser
    for sensor_num in range(1, 9):
        gen_points(server, zone_angles, sport.get_distances(sensor_num-1), sensor_num)
    dbgdata = sport.getDbg()
    #TODO use a "proper" invalid value, as -1 could technically be a valid temperature
    if dbgdata["lsm6_temp"] != -1:
        lsm6_temp.value = f"{round(dbgdata["lsm6_temp"], 1)} °C"
    if dbgdata["lis2_temp"] != -1:
        lis2_temp.value = f"{round(dbgdata["lis2_temp"], 1)} °C"
    if dbgdata["esp_temp"] != -1:
        esp_temp.value = f"{round(dbgdata["esp_temp"])} °C"

#the mainloop thing
def main():
    sport = networkParser(3133)
    sport.start()
    # set up viser server
    server = viser.ViserServer()
    # add sensor frames
    server.scene.add_frame(
            "/sensors/1",
            wxyz=(0.653, 0.271, -0.653, 0.271), #8
            position=(0, 0, 0), #TODO add offset
            show_axes=False
        )
    server.scene.add_frame(
            "/sensors/2",
            wxyz=(0.5, 0.5, -0.5, 0.5), #7
            position=(0, 0, 0), #TODO add offset
            show_axes=False
        )
    server.scene.add_frame(
            "/sensors/3",
            wxyz=(0.271, 0.653, -0.271, 0.653), #6
            position=(0, 0, 0), #TODO add offset
            show_axes=False
        )
    server.scene.add_frame(
            "/sensors/4",
            wxyz=(0, -0.707, -0, -0.707), #5
            position=(0, 0, 0), #TODO add offset
            show_axes=False
        )
    server.scene.add_frame(
            "/sensors/5",
            wxyz=(0.271, -0.653, -0.271, -0.653), #4
            position=(0, 0, 0), #TODO add offset
            show_axes=False
        )
    server.scene.add_frame(
            "/sensors/6",
            wxyz=(0.5, -0.5, -0.5, -0.5), #3
            position=(0, 0, 0), #TODO add offset
            show_axes=False
        )
    server.scene.add_frame(
            "/sensors/7",
            wxyz=(0.635, -0.271, -0.653, -0.271), #2
            position=(0, 0, 0), #TODO add offset
            show_axes=False
        )
    server.scene.add_frame(
            "/sensors/8",
            wxyz=(0.707, 0, -0.707, -0), #1
            position=(0, 0, 0), #TODO add offset
            show_axes=False
        )
    with server.gui.add_folder("Debug data"):
        lsm6_temp = server.gui.add_text(
                "lsm6_temp",
                initial_value="No Data"
                )
        lis2_temp = server.gui.add_text(
                "lis2_temp",
                initial_value="No Data"
                )
        esp_temp = server.gui.add_text(
                "esp_temp",
                initial_value="No Data"
                )
    zone_angles = compute_zone_angles()
    print("Server at http://localhost:8080")
    while True:
        try:
            process_frame(server, zone_angles, sport, lsm6_temp, lis2_temp, esp_temp)
            time.sleep(0.1)
        except KeyboardInterrupt:
            print("Shutting down");
            break
        finally:
            pass
            #TODO stop serial reader


if __name__ == "__main__":
    main()

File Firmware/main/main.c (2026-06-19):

#include  <stdlib.h>
#include "freertos/FreeRTOS.h"
#include "freertos/task.h"
#include "thesis.h"
#include "comms.h"
#include "motion.h"

#define STACK_SIZE 15000


void app_main(void) {
  static uint8_t param;
  TaskHandle_t flexThreadHandle = NULL;
  TaskHandle_t motionThreadHandle = NULL;
  TaskHandle_t commsThreadHandle = NULL;
  //This task gets its' own core, hoping that it will run faster-er (yup)
  xTaskCreatePinnedToCore(thesis_flex_thread,
      "Flex Sensor Readout Thread",
      STACK_SIZE,
      &param,
      1, //HIGH Prio, maybe improves the 15ms gap  - it DOES! do not set it too high, the ESP will not start the USB stack, and then you're a bit screwed
      &flexThreadHandle,
      1 //Core 1
      );
  configASSERT(flexThreadHandle);
  xTaskCreatePinnedToCore(comms_thread,
      "Comms Thread",
      5000,
      &param,
      1, //Higher prio than motion thread
      &commsThreadHandle,
      0 //Core 0
      );
  configASSERT(commsThreadHandle);
  xTaskCreatePinnedToCore(motion_thread,
      "Motion Thread",
      5000,
      &param,
      0, //Low prio
      &motionThreadHandle,
      0 //Core 0
      );
  configASSERT(motionThreadHandle);
};

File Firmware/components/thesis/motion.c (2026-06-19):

#include <stdlib.h>
#include <stdio.h>
#include <stdint.h>
#include <string.h>
#include "driver/spi_master.h"
#include <freertos/FreeRTOS.h>
#include <freertos/task.h>
#include <driver/gpio.h>
#include "esp_log.h"
#include "lsm6dso_reg.h"

#include "motion.h"
#include "comms.h"


#define TAG "motion"


//TODO put in kconfig
#define PIN_NUM_MISO 13
#define PIN_NUM_MOSI 9
#define PIN_NUM_SCLK 12
#define PIN_NUM_LSM6_CS 10
#define PIN_NUM_LIS2_CS 47



// Gubbins for ST library integration
#define BOOT_TIME 100

static int16_t data_raw_acceleration[3];
static int16_t data_raw_angular_rate[3];
static int16_t data_raw_temperature;
static float_t acceleration_mg[3];
static float_t angular_rate_mdps[3];
static float_t temperature_degC;
static uint8_t whoamI, rst;
//static uint8_t tx_buffer[1000];

static int32_t platform_write(void *handle, uint8_t reg, const uint8_t *bufp,
                              uint16_t len);
static int32_t platform_read(void *handle, uint8_t reg, uint8_t *bufp,
                             uint16_t len);
static void platform_delay(uint32_t ms);
//end gubbins


void motion_thread(void *params) {
  ESP_LOGI(TAG, "Motion thread started");
  int err;
  //Set up SPI bus
  spi_device_handle_t lsm6handle;
  spi_device_handle_t lis2handle;
  spi_bus_config_t spi_bus_cfg = {
    .miso_io_num = PIN_NUM_MISO,
    .mosi_io_num = PIN_NUM_MOSI,
    .sclk_io_num = PIN_NUM_SCLK,
    .quadwp_io_num = -1,
    .quadhd_io_num = -1,
  };
  spi_device_interface_config_t lsm6cfg = {
    .clock_speed_hz = 100000,
    .mode = 3,
    .spics_io_num = PIN_NUM_LSM6_CS,
    .queue_size = 5,
    .address_bits=0,
  };
  //TODO start using this. Even though not implemented
  //add to SPI bus so it doesn't accidentally talk
  //due to floating CS pin
  spi_device_interface_config_t lis2cfg = {
    .flags = SPI_DEVICE_POSITIVE_CS,
    .clock_speed_hz = 100000,
    .mode = 0,
    .spics_io_num = PIN_NUM_LIS2_CS,
    .queue_size = 5,
  };
  err = spi_bus_initialize(SPI2_HOST, &spi_bus_cfg, SPI_DMA_CH_AUTO);
  ESP_ERROR_CHECK(err);
  err = spi_bus_add_device(SPI2_HOST, &lsm6cfg, &lsm6handle);
  ESP_ERROR_CHECK(err);
  err = spi_bus_add_device(SPI2_HOST, &lis2cfg, &lis2handle);
  ESP_ERROR_CHECK(err);
  //INIT SENSOR
  stmdev_ctx_t dev_ctx;
  /* Initialize mems driver interface */
  dev_ctx.write_reg = platform_write;
  dev_ctx.read_reg = platform_read;
  dev_ctx.mdelay = platform_delay;
  // I reckon this should be a spi_device_handle_t
  dev_ctx.handle = lsm6handle;

  //SOME MANUAL SPI GUBBINS;
  //get sensor ID: read 1 byte from 0x0F
  spi_transaction_t t;
  char sendbuf[2] = {0};
  char recvbuf[30] = {0};

  sendbuf[0] = 0x0F | 0x80;
  sendbuf[1] = 0x00;

  memset(&t, 0, sizeof(t));
  t.length = 16; //2 byte
  t.rx_buffer = recvbuf;
  t.tx_buffer = sendbuf;
  err = spi_device_transmit(lsm6handle, &t);
  ESP_ERROR_CHECK(err);
  ESP_LOGI(TAG, "GOT 0x%X on 0xF", recvbuf[1]);


  /* Wait sensor boot time */
  platform_delay(BOOT_TIME);
  /* Check device ID */
  lsm6dso_device_id_get(&dev_ctx, &whoamI);

  if (whoamI != LSM6DSO_ID) {
    ESP_LOGE(TAG, "WHOAMI is NOT LSM6DSO_ID (=0x%X), it's 0x%X", LSM6DSO_ID, whoamI);
    return;
  }
  /* Restore default configuration */
  lsm6dso_reset_set(&dev_ctx, PROPERTY_ENABLE);

  do {
    lsm6dso_reset_get(&dev_ctx, &rst);
  } while (rst);

  /* Disable I3C interface */
  lsm6dso_i3c_disable_set(&dev_ctx, LSM6DSO_I3C_DISABLE);
  /* Enable Block Data Update */
  lsm6dso_block_data_update_set(&dev_ctx, PROPERTY_ENABLE);
  /* Set Output Data Rate */
  lsm6dso_xl_data_rate_set(&dev_ctx, LSM6DSO_XL_ODR_12Hz5);
  lsm6dso_gy_data_rate_set(&dev_ctx, LSM6DSO_GY_ODR_12Hz5);
  /* Set full scale */
  lsm6dso_xl_full_scale_set(&dev_ctx, LSM6DSO_2g);
  lsm6dso_gy_full_scale_set(&dev_ctx, LSM6DSO_2000dps);
  /* Configure filtering chain(No aux interface)
   * Accelerometer - LPF1 + LPF2 path
   */
  lsm6dso_xl_hp_path_on_out_set(&dev_ctx, LSM6DSO_LP_ODR_DIV_100);
  lsm6dso_xl_filter_lp2_set(&dev_ctx, PROPERTY_ENABLE);

  /* Read samples in polling mode (no int) */
  struct comms_queue_item accel_msg = {
    .type = COMMS_QUEUE_ITEM_TYPE_ACCEL,
  };
  struct comms_queue_item gyro_msg = {
    .type = COMMS_QUEUE_ITEM_TYPE_GYRO,
  };
  struct comms_queue_item mag_msg = {
    .type = COMMS_QUEUE_ITEM_TYPE_MAG,
  };
  struct comms_queue_item lsm_temp_msg = {
    .type = COMMS_QUEUE_ITEM_TYPE_LSM_TEMP,
  };
  TickType_t last_sample_tick;
  const TickType_t motion_sample_freq = pdMS_TO_TICKS(100); //100hz possible?? Not without flag data ready get retry stuff. MAYBE ALSO USE INTERRUPTS FOR THIS?
  while (1) {
    //Lovely, the loop now runs at a set frequency.
    //Not so lovely: it only TRIES to get data at this frequency
    //which means that if a sensor isn't ready, we "skip" a sample
    //TODO MAYBE fix, if it's a big issue
    //FIX simpler: just try a few times lol (like LIDAR module)
    //FIX bestest: use the interrupts with a DRDY semaphore
    vTaskDelayUntil(&last_sample_tick, motion_sample_freq);

    uint8_t reg;
    /* Read output only if new xl value is available */
    lsm6dso_xl_flag_data_ready_get(&dev_ctx, &reg);

    if (reg) {
      gettimeofday(&accel_msg.tv_now, NULL);
      /* Read acceleration field data */
      memset(data_raw_acceleration, 0x00, 3 * sizeof(int16_t));
      lsm6dso_acceleration_raw_get(&dev_ctx, data_raw_acceleration);
      accel_msg.accel_message.accel_x = lsm6dso_from_fs2_to_mg(data_raw_acceleration[0]);
      accel_msg.accel_message.accel_y = lsm6dso_from_fs2_to_mg(data_raw_acceleration[1]);
      accel_msg.accel_message.accel_z = lsm6dso_from_fs2_to_mg(data_raw_acceleration[2]);
      commsPost(&accel_msg);

      /*
      acceleration_mg[0] =
        lsm6dso_from_fs2_to_mg(data_raw_acceleration[0]);
      acceleration_mg[1] =
        lsm6dso_from_fs2_to_mg(data_raw_acceleration[1]);
      acceleration_mg[2] =
        lsm6dso_from_fs2_to_mg(data_raw_acceleration[2]);
      ESP_LOGI(TAG, "Acceleration [mg]:%4.2f\t%4.2f\t%4.2f\r\n",
          acceleration_mg[0], acceleration_mg[1], acceleration_mg[2]);
          */

    }

    lsm6dso_gy_flag_data_ready_get(&dev_ctx, &reg);
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
